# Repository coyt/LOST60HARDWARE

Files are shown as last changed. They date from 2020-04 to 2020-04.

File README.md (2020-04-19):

# LOST60HARDWARE
Hardware design files for LOST60 Bluetooth Mechanical Keyboard

<p align="center">

</p>

<p align="center">

</p>

#### LOST60 PCB Version 2.0 (SPRING 2020)
<p align="center">
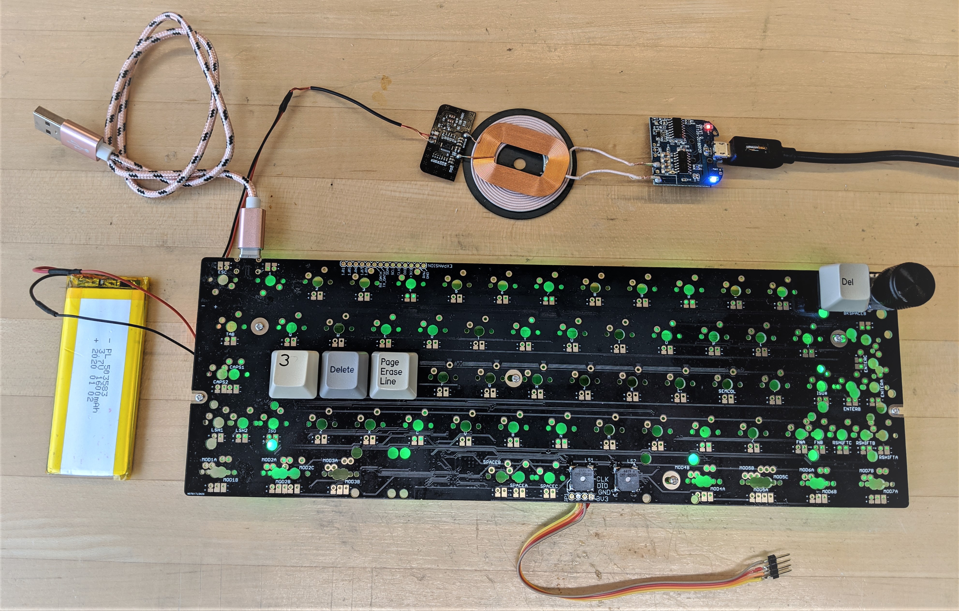
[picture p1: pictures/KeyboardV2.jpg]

</p>

#### LOST60 PCB Version 1.0 (FALL 2019)
<p align="center">

</p>

*The Ultimate Hackable Bluetooth Mechanical Keyboard*

#### Overview

Hardware design files for the LOST60 Bluetooth 60% Mechanical Keyboard PCB. The PCB utilizes a Nordic Semiconductor [nrf52840 bluetooth SoC](https://www.nordicsemi.com/?sc_itemid=%7B2DC10BA5-A76E-40F8-836E-E2FC65803A71%7D) (Rigado BMD-340 module) as the sole processor.

#### PCB Artwork
<p align="center">
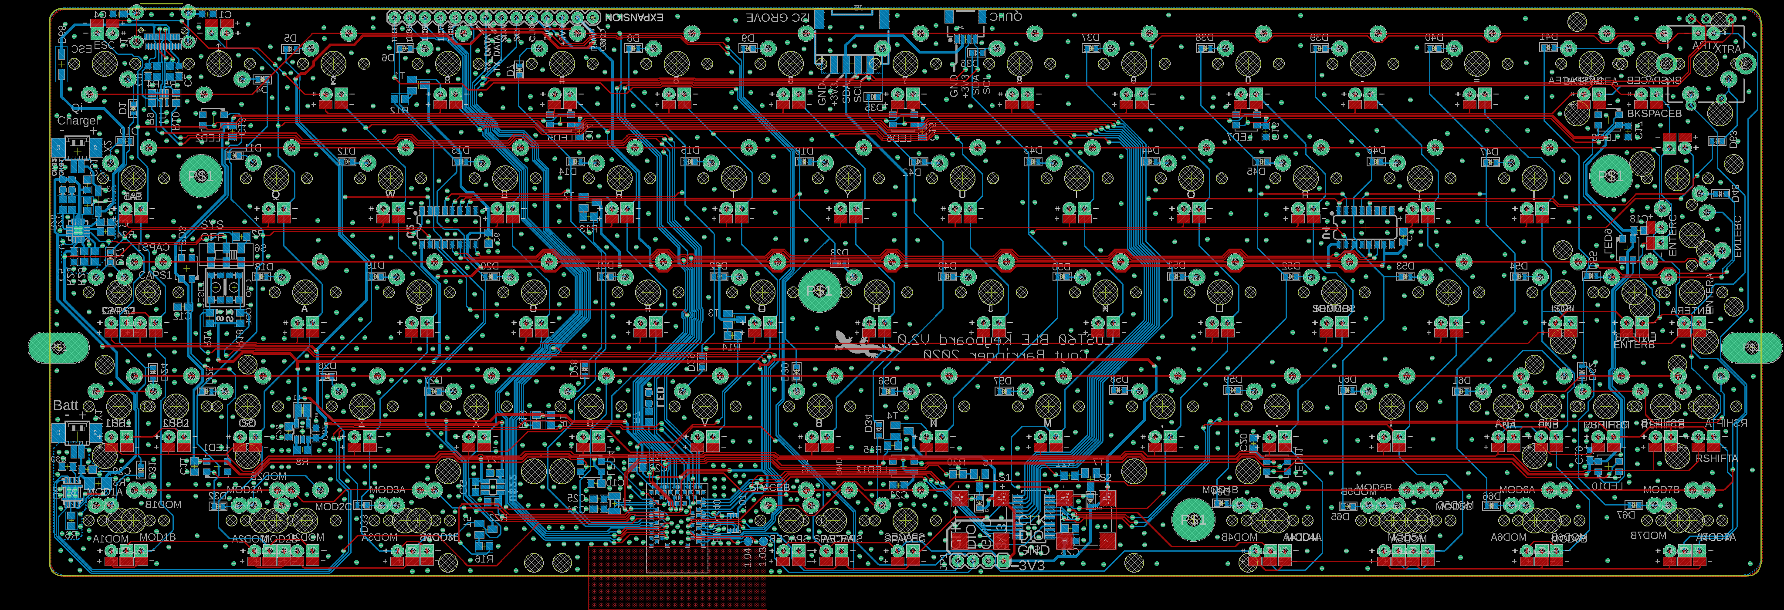
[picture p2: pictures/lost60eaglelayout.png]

</p>

#### 3D Modeling
<p align="center">
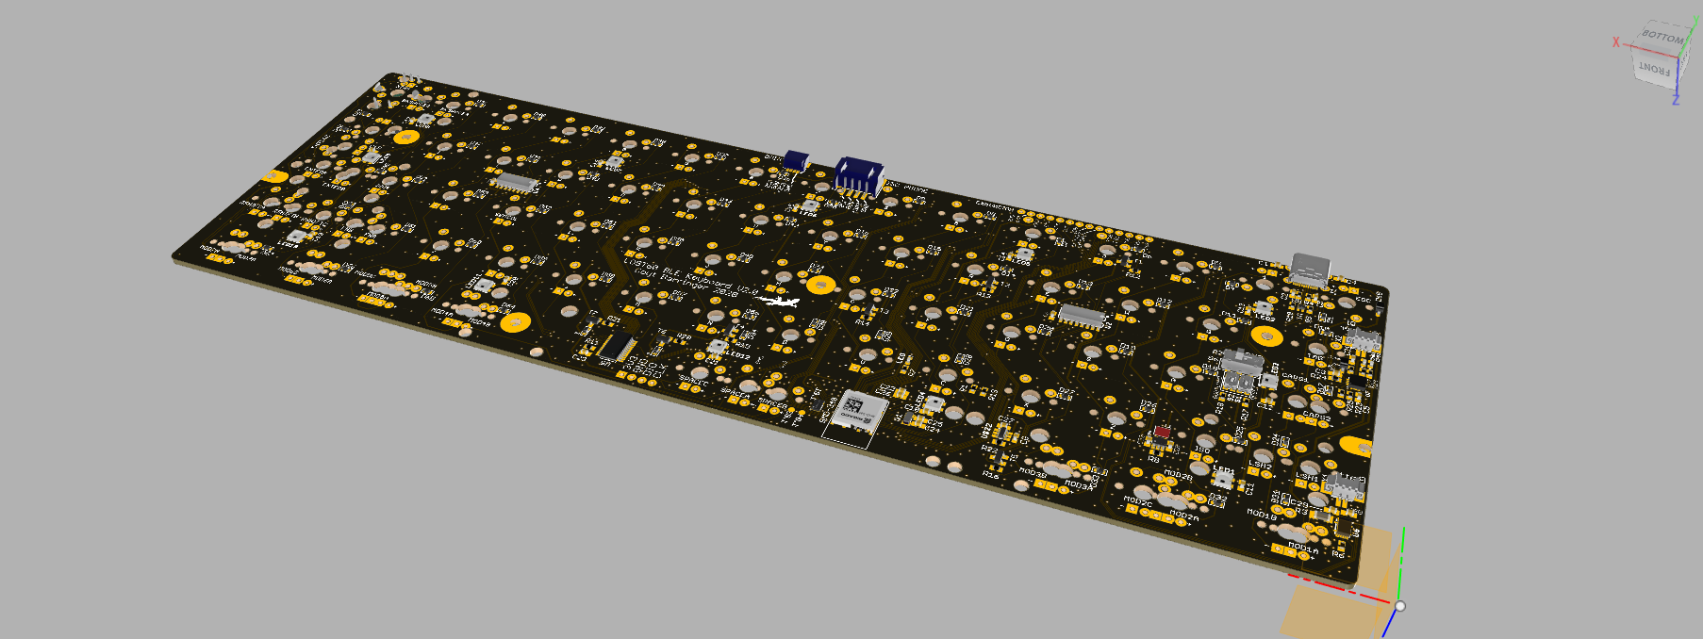
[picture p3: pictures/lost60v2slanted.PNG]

</p>

<p align="center">
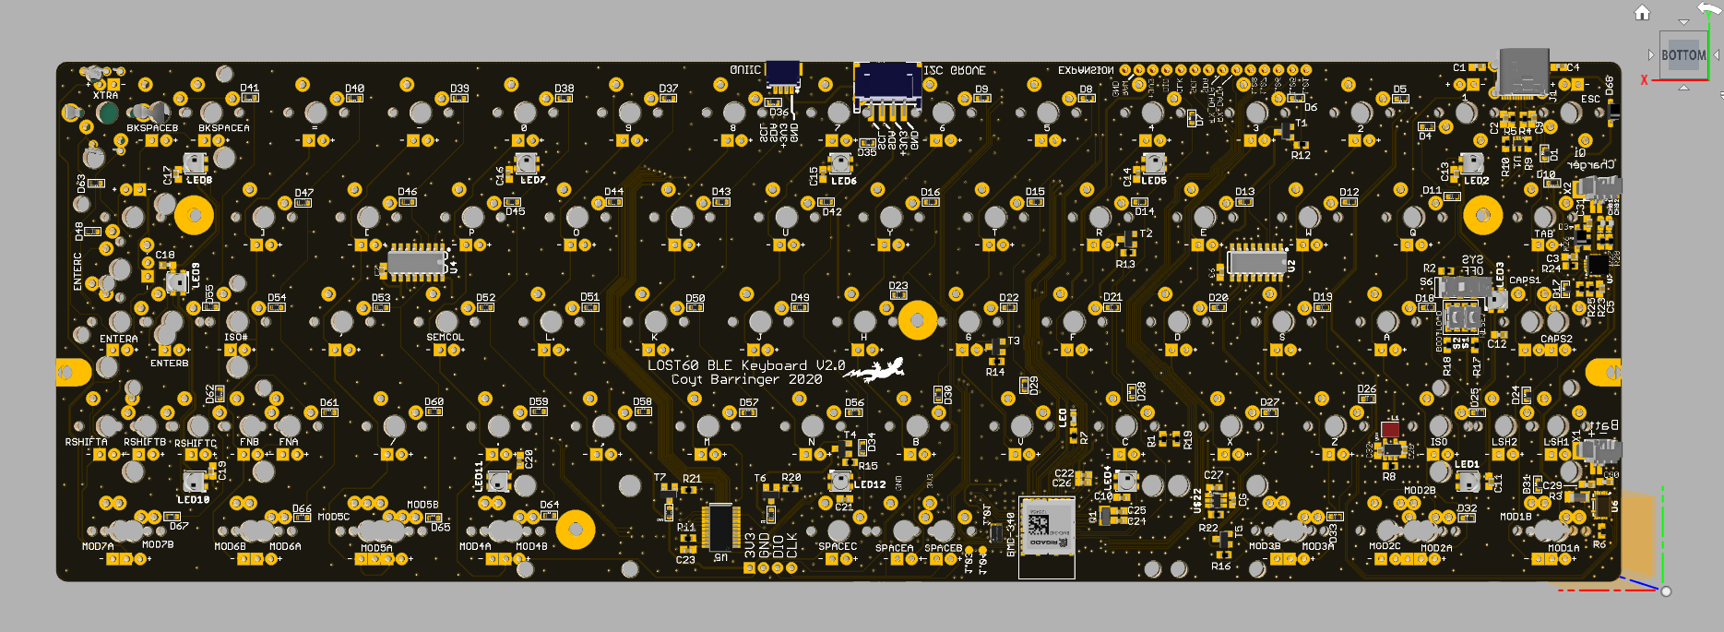
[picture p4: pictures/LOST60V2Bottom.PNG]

</p>

<p align="center">
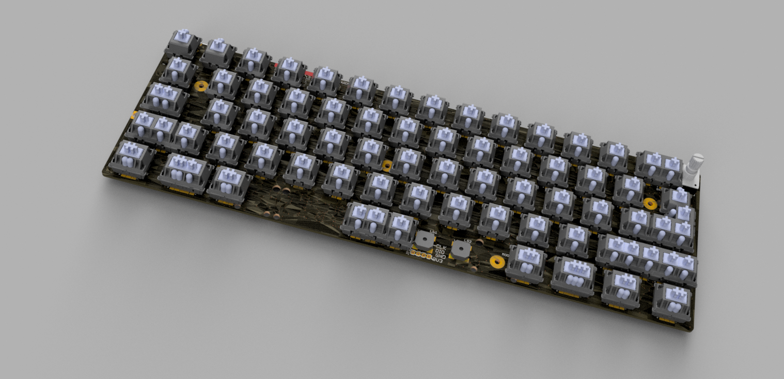
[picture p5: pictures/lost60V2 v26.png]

</p>

#### Version 2.0 System Diagram

<p align="center">
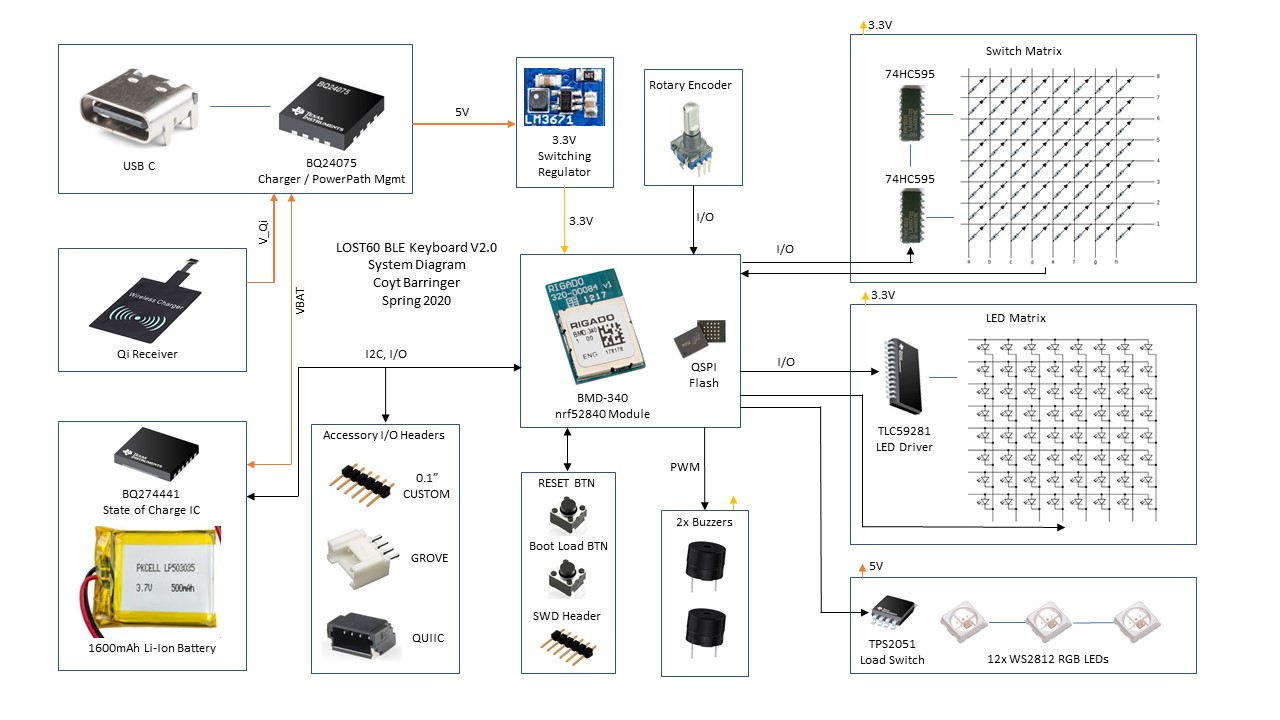
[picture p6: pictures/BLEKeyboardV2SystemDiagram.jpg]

</p>

#### Hardware Features
* 60% Mechanical Keyboard design based on GH60 Layout
* USBC connector
* Bluetooth 5.0 support
* Full RGB underlighting with "neopixels"
* Independently addressable single color key backlingting
* Qi wireless charging
* Advanced battery charging and management circuitry
* Rotary encoder and TWO speakers for Synthesizer features (under development)
* Several expansion ports (QUIIC, GROVE, CUSTOM)

#### Planned Hardware Updates

- [x] Add coulomb counting IC / improve voltage and power measurement   (Complete in V2.0)
- [ ] Improve backlighting LED brightness 
- [x] Extend USB C connector out a bit                                  (Complete in V2.0)
- [x] Fix underlighting load switch fly wire                            (Complete in V2.0)
- [x] Fix LiPo charger ground pour problem & improve charge rate        (Complete in V2.0)
- [x] Remove onboard Lithium protection IC                              (Complete in V2.0)
- [ ] Add physical power switch connection point 
- [ ] Change wiring so I/O emulates Feather nrf52840 board
- [x] Add QSPI memory chip                                              (Complete in V2.0)

#### Development Setup

This design was created using Eagle PCB for schematic capture and PCB layout and routing. Fusion 360 was used to generate CAD model of board before manufacture.

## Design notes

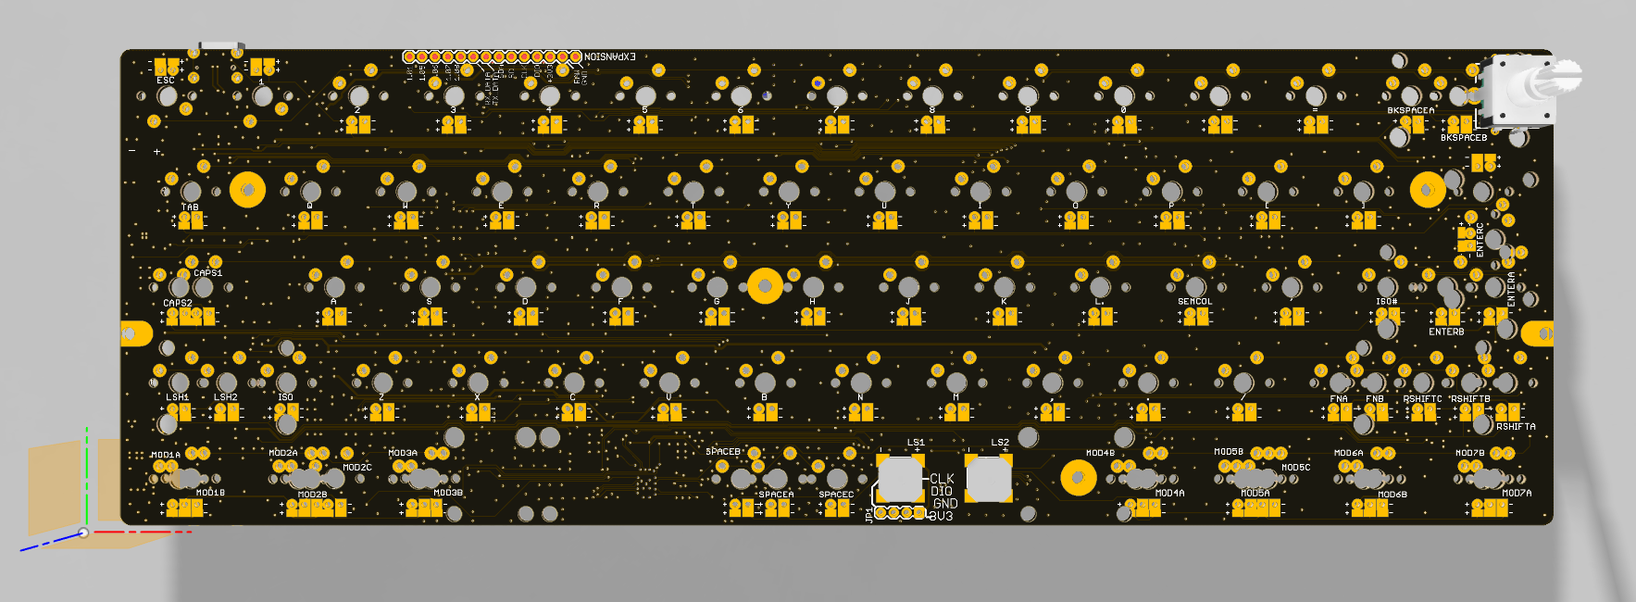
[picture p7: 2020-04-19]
pictures/LOST60V2.PNG

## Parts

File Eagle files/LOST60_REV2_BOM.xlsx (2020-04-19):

Qty | Value | Device | Package | Digikey Part Number | Price Per Part | Part Qty. for price | Total Price | Parts | Description
67 |  | DIODESOD-523 | SOD-523 | 1N4448XTPMSCT-ND | 0.02319 | 1000 | #REF! | D1, D2, D4, D5, D6, D7, D8, D9, D10, D11, D12, D13, D14, D15, D16, D17, D18, D19, D20, D21, D22, D23, D24, D25, D26, D27, D28, D29, D30, D31, D32, D33, D34, D35, D36, D37, D38, D39, D40, D41, D42, D43, D44, D45, D46, D47, D48, D49, D50, D51, D52, D53, D54, D55, D56, D57, D58, D59, D60, D61, D62, D63, D64, D65, D66, D67, D69 | Diode
1 |  | DX07S024JJ2_USB_TYPE-C | DX07S0224JJ2_USB-C | 670-2794-1-ND | 2.372 | 10 | #REF! | J1 | JAE DX07S024JJ2 USB Type-C Connector
1 |  | QWIIC_CONNECTORJS-1MM | 1X04_1MM_RA | 455-1804-1-ND | 0.569 | 10 | #REF! | J4 | SparkFun I2C Standard Qwiic Connector
1 | 0 | R-US_R0603 | R0603 | 311-0.0GRCT-ND | 0.019 | 10 | #REF! | R24 | RESISTOR, American symbol
1 | 0.01 | R-US_R1206 | R1206 | 408-1570-1-ND | 0.385 | 10 | #REF! | R3 | RESISTOR, American symbol
12 | 0.1uF | C-USC0603K | C0603K | 399-1099-1-ND | 0.01152 | 500 | #REF! | C10, C11, C12, C13, C14, C15, C16, C17, C18, C19, C20, C21 | CAPACITOR, American symbol
1 | 0.47uF | C-USC0603K | C0603K | 1276-2082-1-ND | 0.073 | 10 | #REF! | C30 | CAPACITOR, American symbol
1 | 1.1k | R-US_R0603 | R0603 | RMCF0603FT1K10CT-ND | 0.016 | 10 | #REF! | R26 | RESISTOR, American symbol
2 | 100k | R-US_R0603 | R0603 | RR08P100KDCT-ND | 0.093 | 10 | #REF! | R8, R22 | RESISTOR, American symbol
2 | 100pF | C-USC0603K | C0603K | 1292-1644-1-ND | 0.028 | 10 | #REF! | C1, C4 | CAPACITOR, American symbol
3 | 10k | R-US_R0603 | R0603 | 311-10KGRCT-ND | 0.019 | 10 | #REF! | R17, R18, R23 | RESISTOR, American symbol
3 | 10uF | C-USC0603K | C0603K | 587-5869-1-ND | 0.0451 | 100 | #REF! | C5, C26, C31,C32 | CAPACITOR, American symbol
2 | 15pF | C-USC0603K | C0603K | 1292-1487-1-ND | 0.028 | 10 | #REF! | C24, C25 | CAPACITOR, American symbol
2 | 4.7k | R-US_R0603 | R0603 | 311-4.7KGRCT-ND | 0.019 | 10 | #REF! | R1, R19
4 | 1k | R-US_R0603 | R0603 | 311-1.0KGRCT-ND | 0.0077 | 100 | #REF! | R2, R7, R27, R28 | RESISTOR, American symbol
6 | 1uF | C-USC0603K | C0603K | 1276-6524-1-ND | 0.0186 | 100 | #REF! | C3, C6, C7, C22, C23, C27, C29 | CAPACITOR, American symbol
1 | 2.2uH/NRH2412T2R2MNGH | MICROBUILDER_INDUCTORNRH2412T | MICROBUILDER_INDUCTOR_TAIYOYUDEN_NRH2412T | 587-3443-1-ND | 0.203 | 10 | #REF! | L1 | Inductors
1 | 2.7k | R-US_R0603 | R0603 | A129693CT-ND | 0.03 | 10 | #REF! | R6 | RESISTOR, American symbol
1 | 22uF | C-USC0603K | C0603K | 1276-2868-1-ND | 0.173 | 10 | #REF! | C28 | CAPACITOR, American symbol
2 | 3.3uF | C-USC0603K | C0603K | 399-5502-1-ND | 0.171 | 10 | #REF! | C2, C9 | CAPACITOR, American symbol
2 | 30 | R-US_R0603 | R0603 | 311-30GRCT-ND | 0.019 | 10 | #REF! | R9, R10 | RESISTOR, American symbol
1 | 32.768kHz | KX-327-NHF | 3.2X1.5 | 300-8879-1-ND | 0.446 | 10 | #REF! | Q1 | Tuning Fork Crystals (kHz) SMD:
1 | 4.7uF | C-USC0603 | C0603 | 1276-1045-1-ND | 0.055 | 10 | #REF! | CG | CAPACITOR, American symbol
10 | 5.1k | R-US_R0603 | R0603 | P5.10KHCT-ND | 0.0234 | 100 | #REF! | R4, R5, R11, R12, R13, R14, R15, R16, R20, R21 | RESISTOR, American symbol
1 | 590 | R-US_R0603 | R0603 | 311-590HRCT-ND | 0.023 | 10 | #REF! | R25 | RESISTOR, American symbol
7 | BC848 | BC848 | SOT23 | BC848BLT1GOSCT-ND | 0.116 | 10 | #REF! | T1, T2, T3, T4, T5, T6, T7 | NPN TRANSISTOR
1 | BMD-340 | BMD-340 | BMD-340 | 672-BMD-340-A-R-00CT-ND | 12.07 | 10 | #REF! | BMD-340
1 | BQ24075 | BQ24075 | PVQFN-N16 | 296-25609-1-ND | 2.042 | 10 | #REF! | U7 | Texas Instruments BQ24075 LiPo Battery Chargerand Power-Path Management IC
1 | BQ27441-G1 | BQ27441-G1 | PDSO-N12 | 296-39941-1-ND | 2.353 | 10 | #REF! | U6 | Texas Instruments BQ27441-G1 LiPo Battery Fuel Gauge
2 | CMT-8530S-SMT | CMT-8530S-SMT | CUI_CMT-8530S-SMT | 102-3736-1-ND | 2.202 | 25 | #REF! | LS1, LS2 | 8.5 mm, 3.6 Vo-p, 90 dB, Surface Mount (SMT), Magnetic Audio Transducer Buzzer
1 | GD25Q16CEIGR | MICROBUILDER_SPIFLASH_8PINUX | MICROBUILDER_USON8 | 1970-1011-1-ND | 0.552 | 10 | #REF! | U3 | SOIC8 SPI Flash
1 | LM3671 | LM3671 | SOT23-5 | LM3671MF-3.3/NOPBCT-ND | 1.282 | 10 | #REF! | U$38 | Texas Instruments LM3671, LM3671Q 2MHz, 600mA Step-Down DC-DC Converter
2 | MBR120 | D-FILL-SOD123 | SOD123 | SL22PL-TPMSCT-ND | 0.313 | 10 | #REF! | D3, D68 | DIODE
2 | MOLEX_53261-02 | MOLEX_53261-02 | 53261-02 | WM7620CT-ND | 0.86 | 10 | #REF! | X1, X2 | CONNECTOR
2 | MOMENTARY-SWITCH-SPST-SMD-4.6X2.8MM | MOMENTARY-SWITCH-SPST-SMD-4.6X2.8MM | TACTILE_SWITCH_SMD_4.6X2.8MM | CKN11065CT-ND | 0.432 | 10 | #REF! | S1, S2 | Momentary Switch (Pushbutton) - SPST
2 | ORANGE | LED0603 | LED-0603 | SML-D12D1WT86CT-ND | 0.155 | 10 | #REF! | CHG1, CHG2 | LED (Generic)
1 | RED | LED0603 | LED-0603 | 732-4978-1-ND | 0.14 | 1 | #REF! | LED | LED (Generic)
2 | SN74HC595D | 74HC595D | SO16 | 296-14857-1-ND | 0.34 | 10 | #REF! | U2, U4 | 8-Bit Shift Register (Serial to Parallel)
1 | TLC59281DBQR | TLC59281DBQR | SOP63P600X175-28N | 296-25789-6-ND | 1.149 | 10 | #REF! | U5 | 16-Channel LED Driver
1 | TPD3E001DRLR | TPD3E001DRLR | SOT50P160X60-5N | 296-21885-1-ND | 0.433 | 10 | #REF! | U1 | LOW-CAPACITANCE 3-CHANNEL Â±15-kV ESD-PROTECTION ARRAY FOR HIGH-SPEED DATA INTERFACES
1 | TPS22810* | TPS22810* | SOT23-6 | 296-45297-1-ND | 0.545 | 10 | #REF! | U$22 | The TPS22810 is a single channel load switch with
1 | 4P-SMD-2.0-90D | GROVE-CONNECTOR-SMD-90D(4+2P-2.0) | HW4-SMD-2.0-90D |  |  |  | #REF! | J5 | 320110032
1 | JS202011JCQN | JS202011JCQN | JS202011JCQN |  |  |  | #REF! | S6
12 | WS2812B3535 | WS2812B3535 | LED3535 |  |  |  | #REF! | LED1, LED2, LED3, LED4, LED5, LED6, LED7, LED8, LED9, LED10, LED11, LED12
1 | ENCODER-SWITCH-MOD1 | ENCODER-SWITCH-MOD1 | ROTARY_ENC_PLAIN-MOD1 | PEC11R-4220K-S0024-ND | 1.56600 | 10 | #REF! | S4 | Rotary Encoder w/ Select Switch
1 |  | M14 | 1X14 |  |  |  | #REF! | JP2 | Header 14
 | Top components: | 95
 | Bottom components: | 173 |  |  |  |  | #REF!
 | Total Pads: | 1124

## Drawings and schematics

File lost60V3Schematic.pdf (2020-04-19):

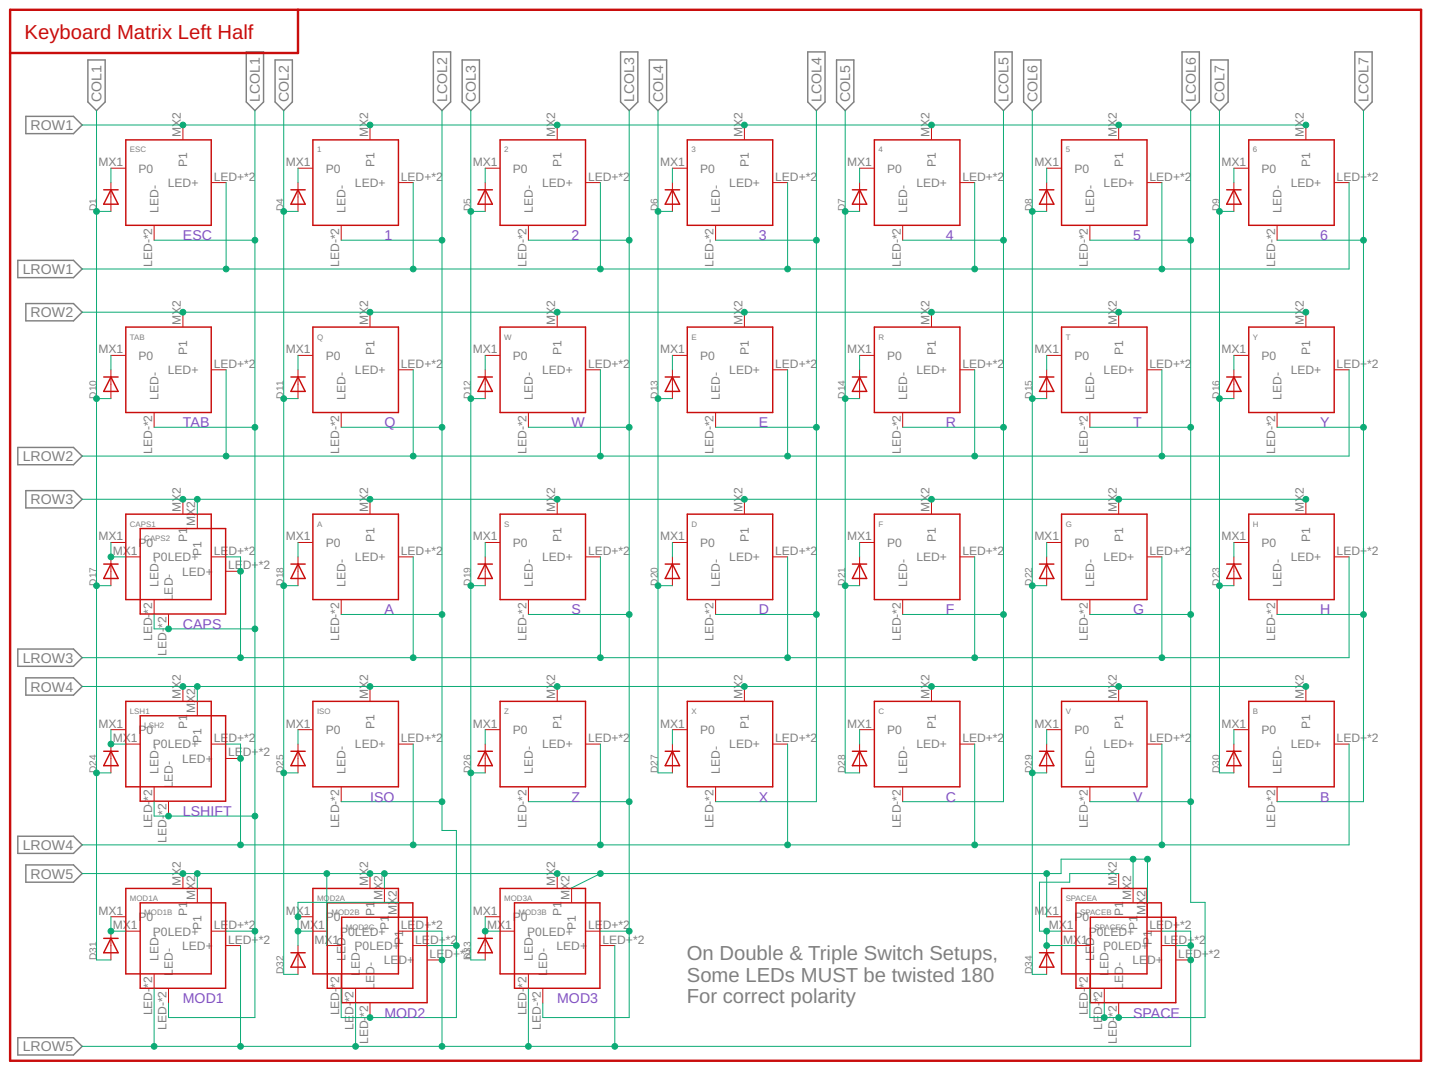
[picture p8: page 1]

Keyboard Matrix Left Half

On Double & Triple Switch Setups, Some LEDs MUST be twisted 180

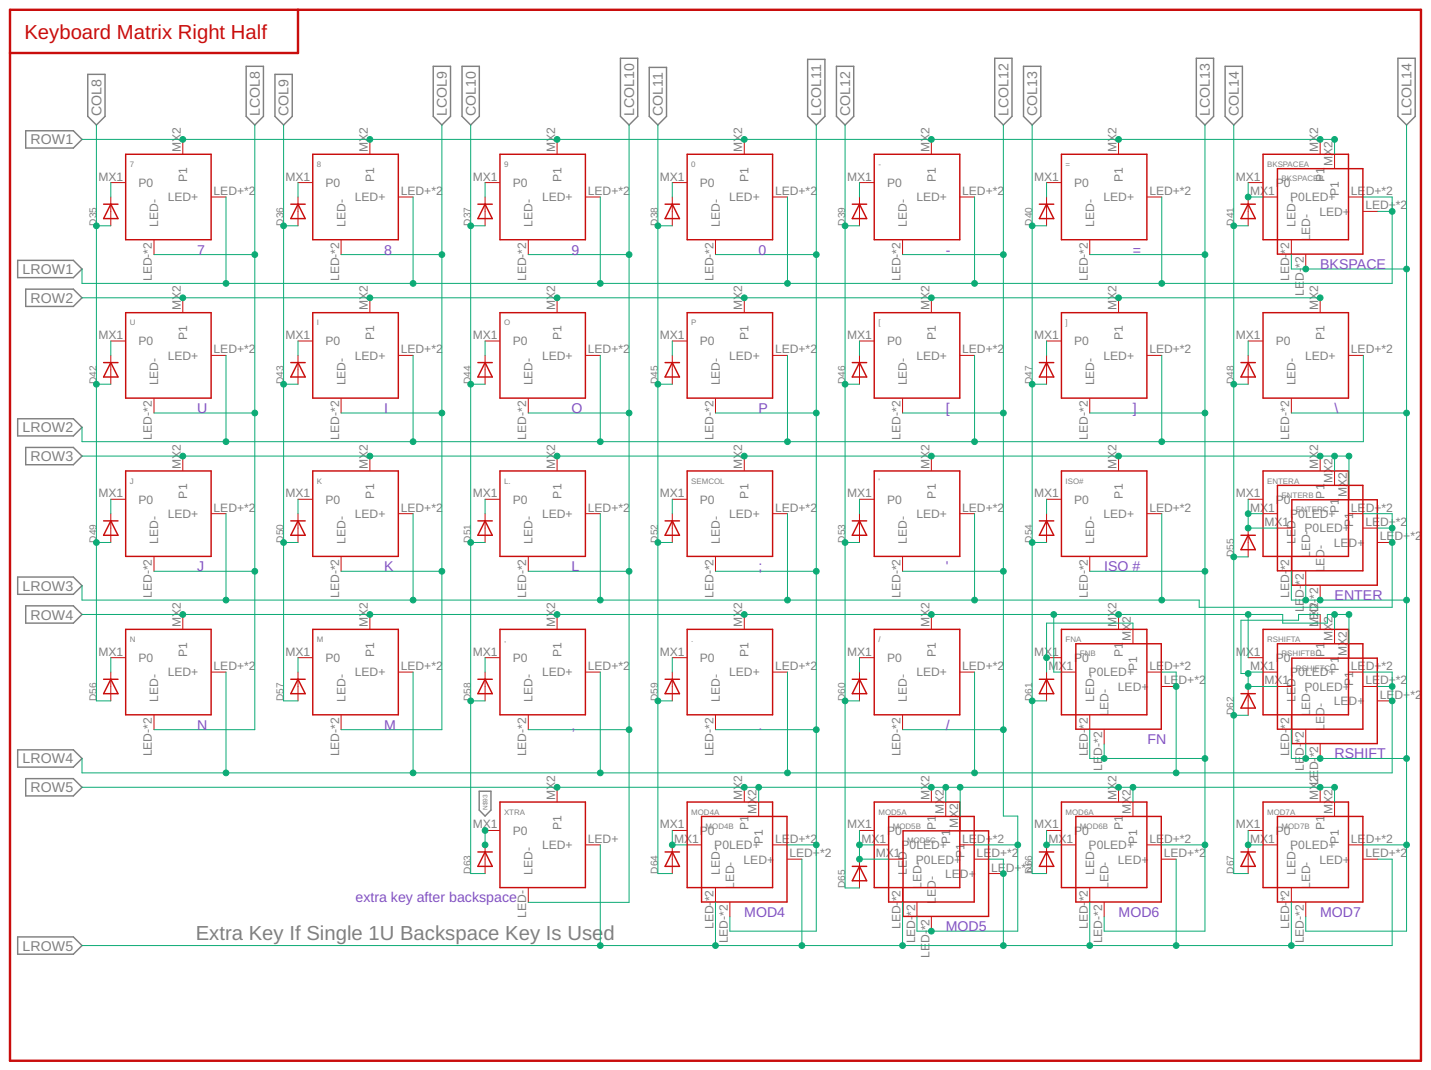
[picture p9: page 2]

Keyboard Matrix Right Half

ENTERB
LED+ | LED+*2

Extra Key If Single 1U Backspace Key Is Used

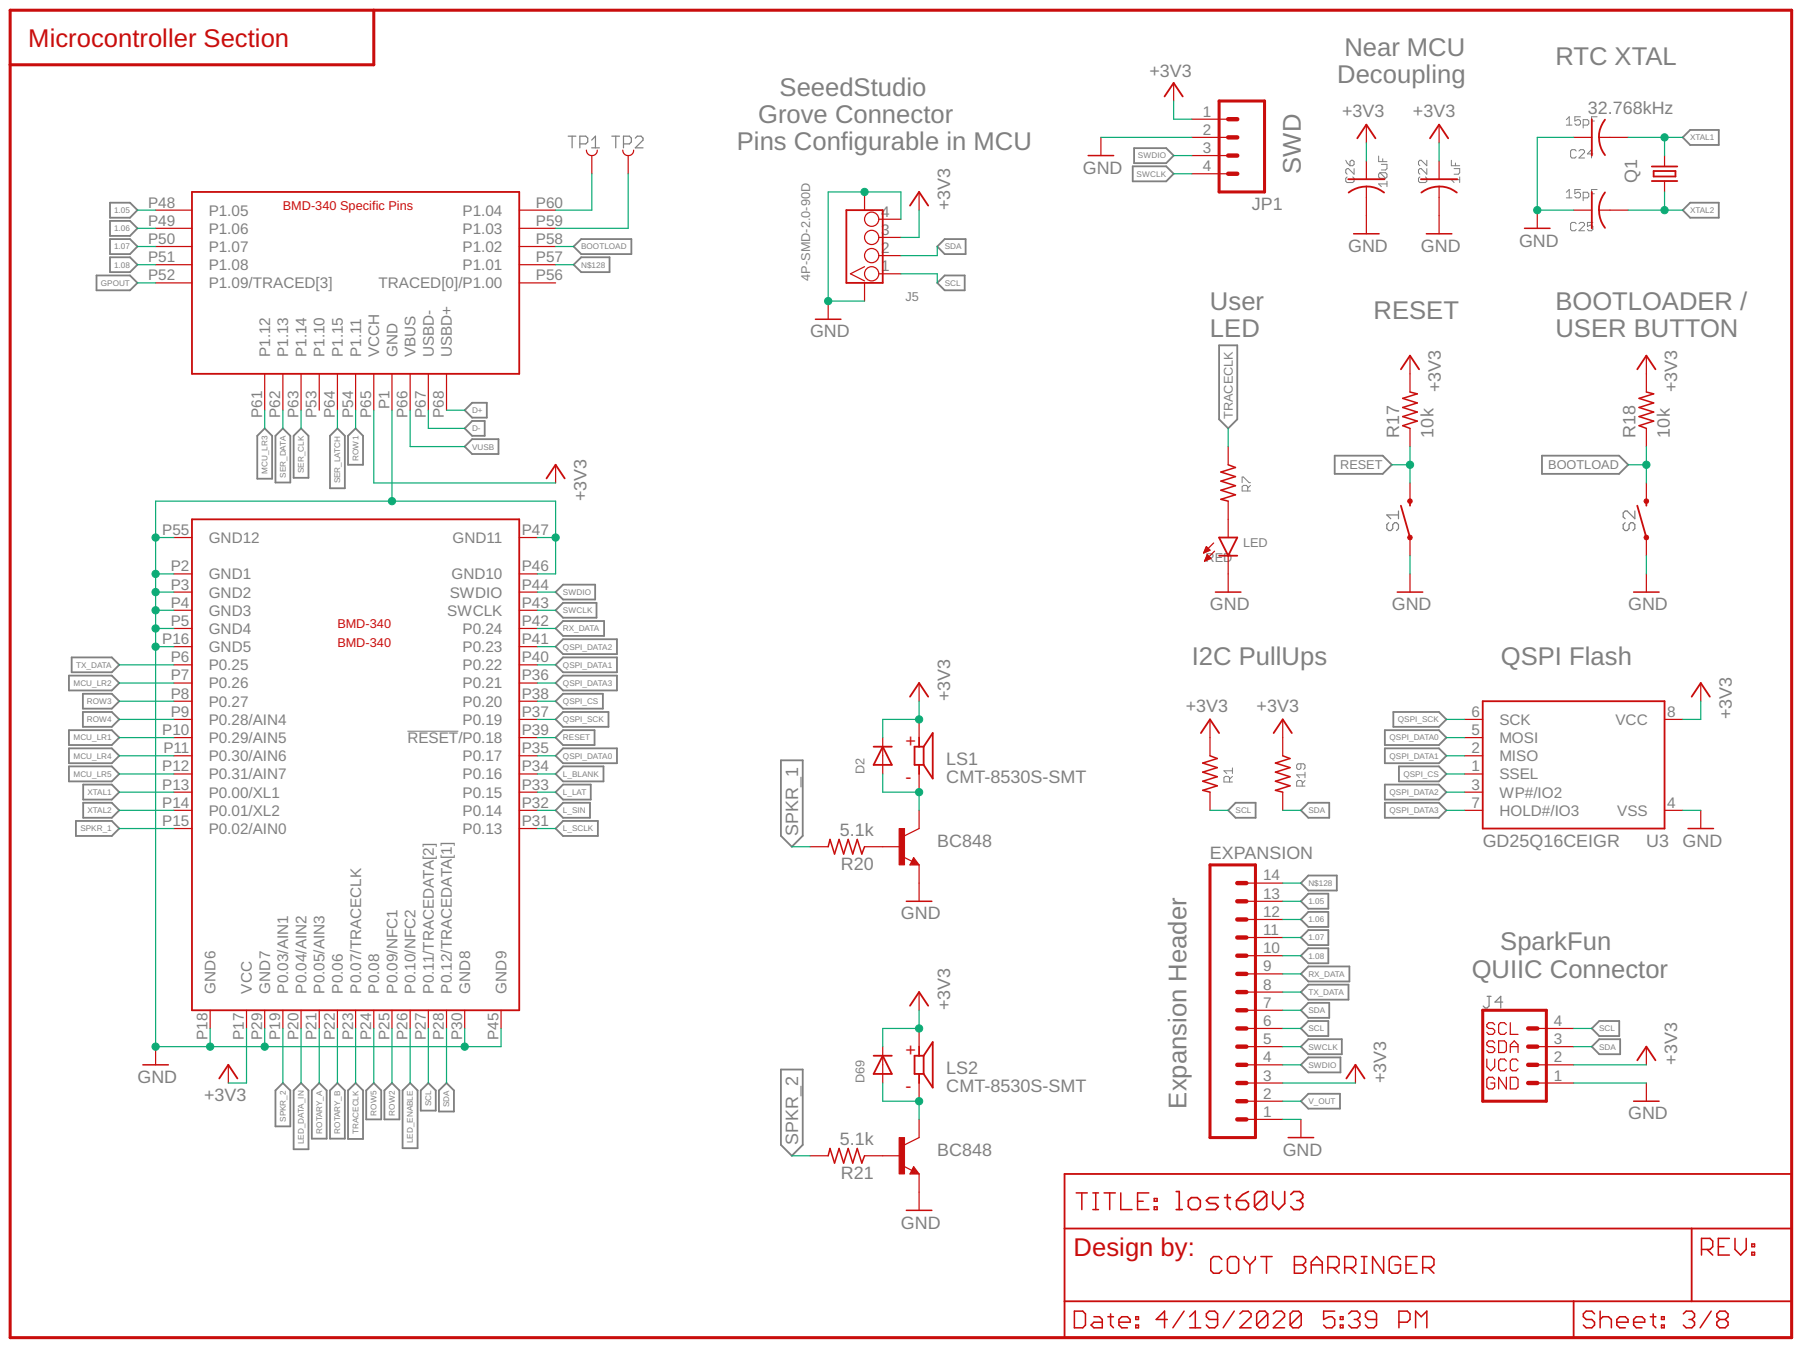
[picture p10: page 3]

SeeedStudio
Grove Connector
Pins Configurable in MCU

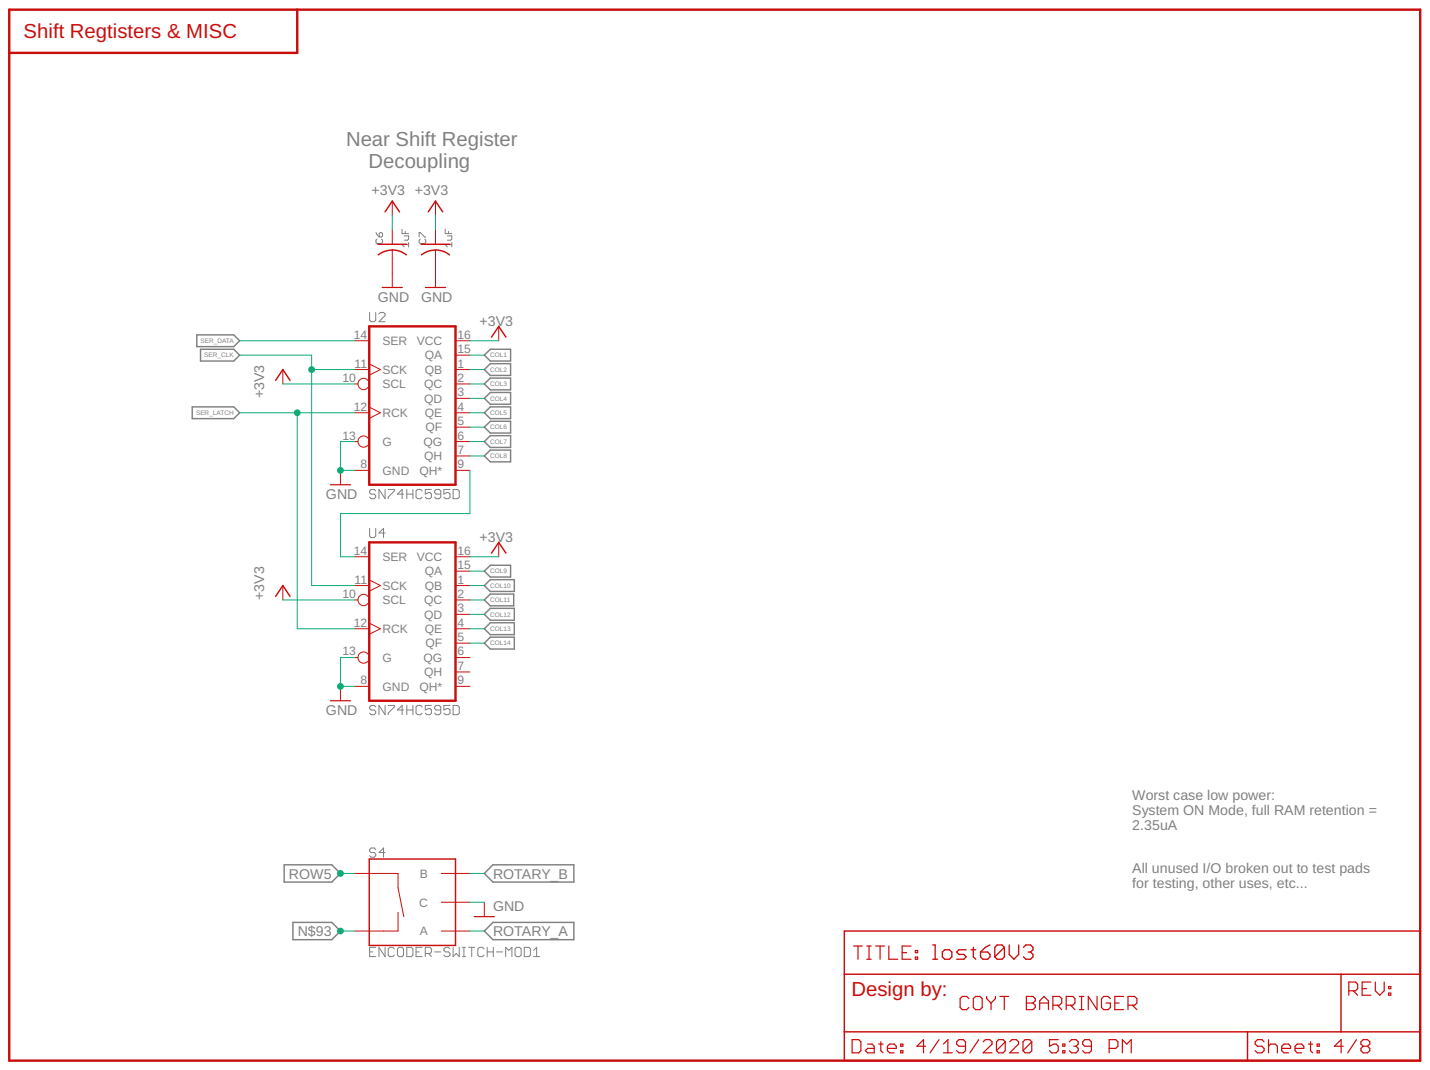
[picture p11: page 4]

for testing, other uses, etc... Worst case low power: System ON Mode, full RAM retention =

All unused I/O broken out to test pads

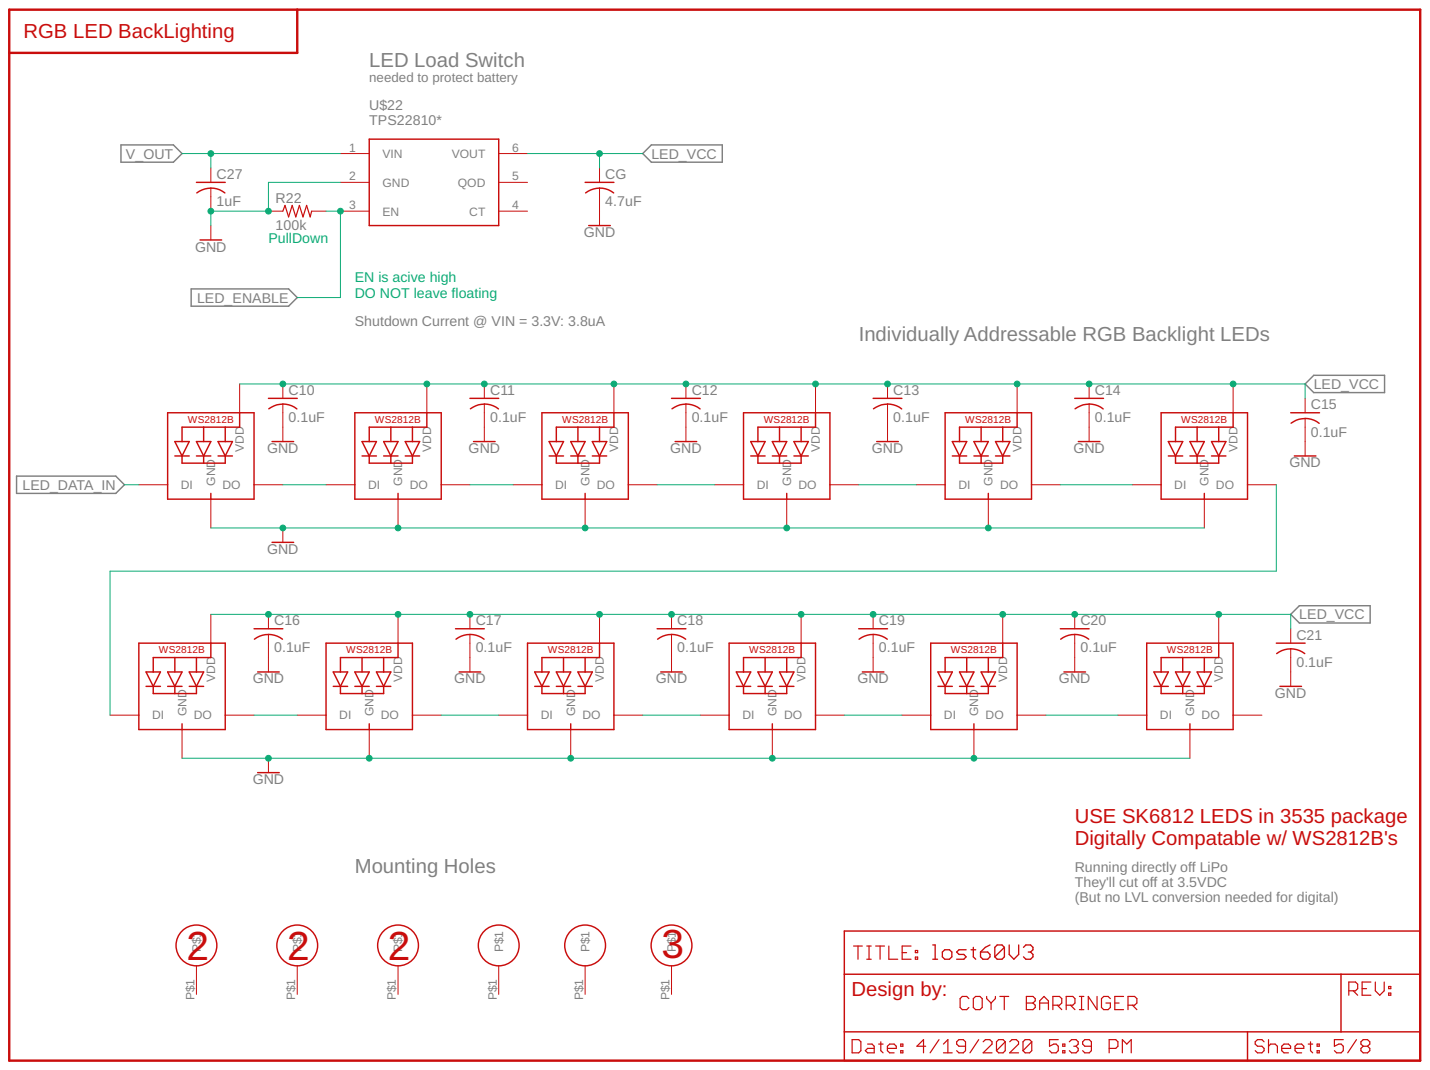
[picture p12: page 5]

LED Load Switch
needed to protect battery

EN is acive high
DO NOT leave floating

Individually Addressable RGB Backlight LEDs

USE SK6812 LEDS in 3535 package
Digitally Compatable w/ WS2812B's

Running directly off LiPo They'll cut off at 3.5VDC

(But no LVL conversion needed for digital)

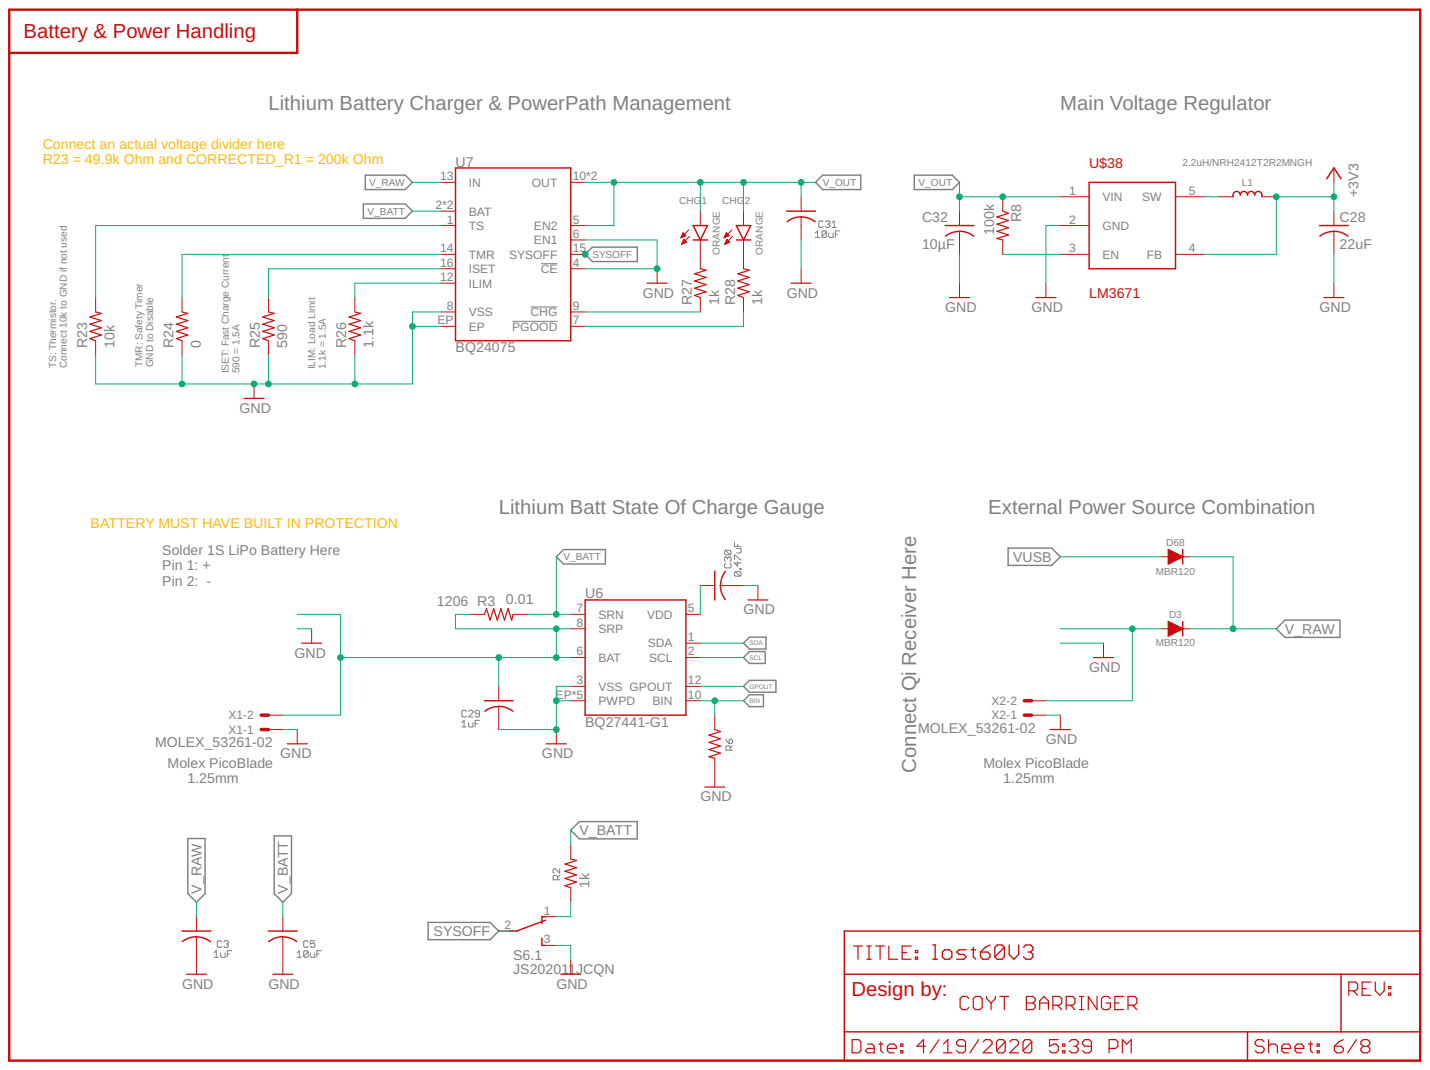
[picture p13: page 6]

Connect an actual voltage divider here R23 = 49.9k Ohm and CORRECTED_R1 = 200k Ohm

TS: Thermistor. Connect 10k to GND if not used TMR: Safety Timer GND to Disable

ISET: Fast Charge Current 590 = 1.5A

Lithium Batt State Of Charge Gauge

External Power Source Combination

BATTERY MUST HAVE BUILT IN PROTECTION

Solder 1S LiPo Battery Here Pin 1: + Pin 2: -

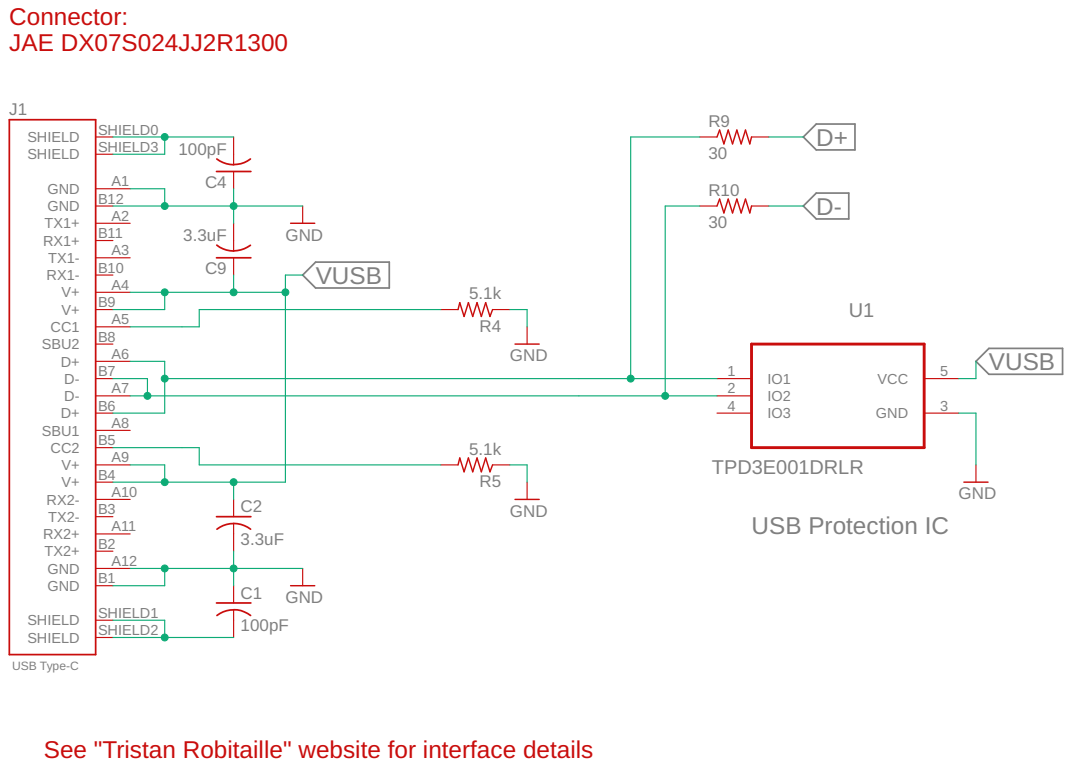
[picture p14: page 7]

See "Tristan Robitaille" website for interface details

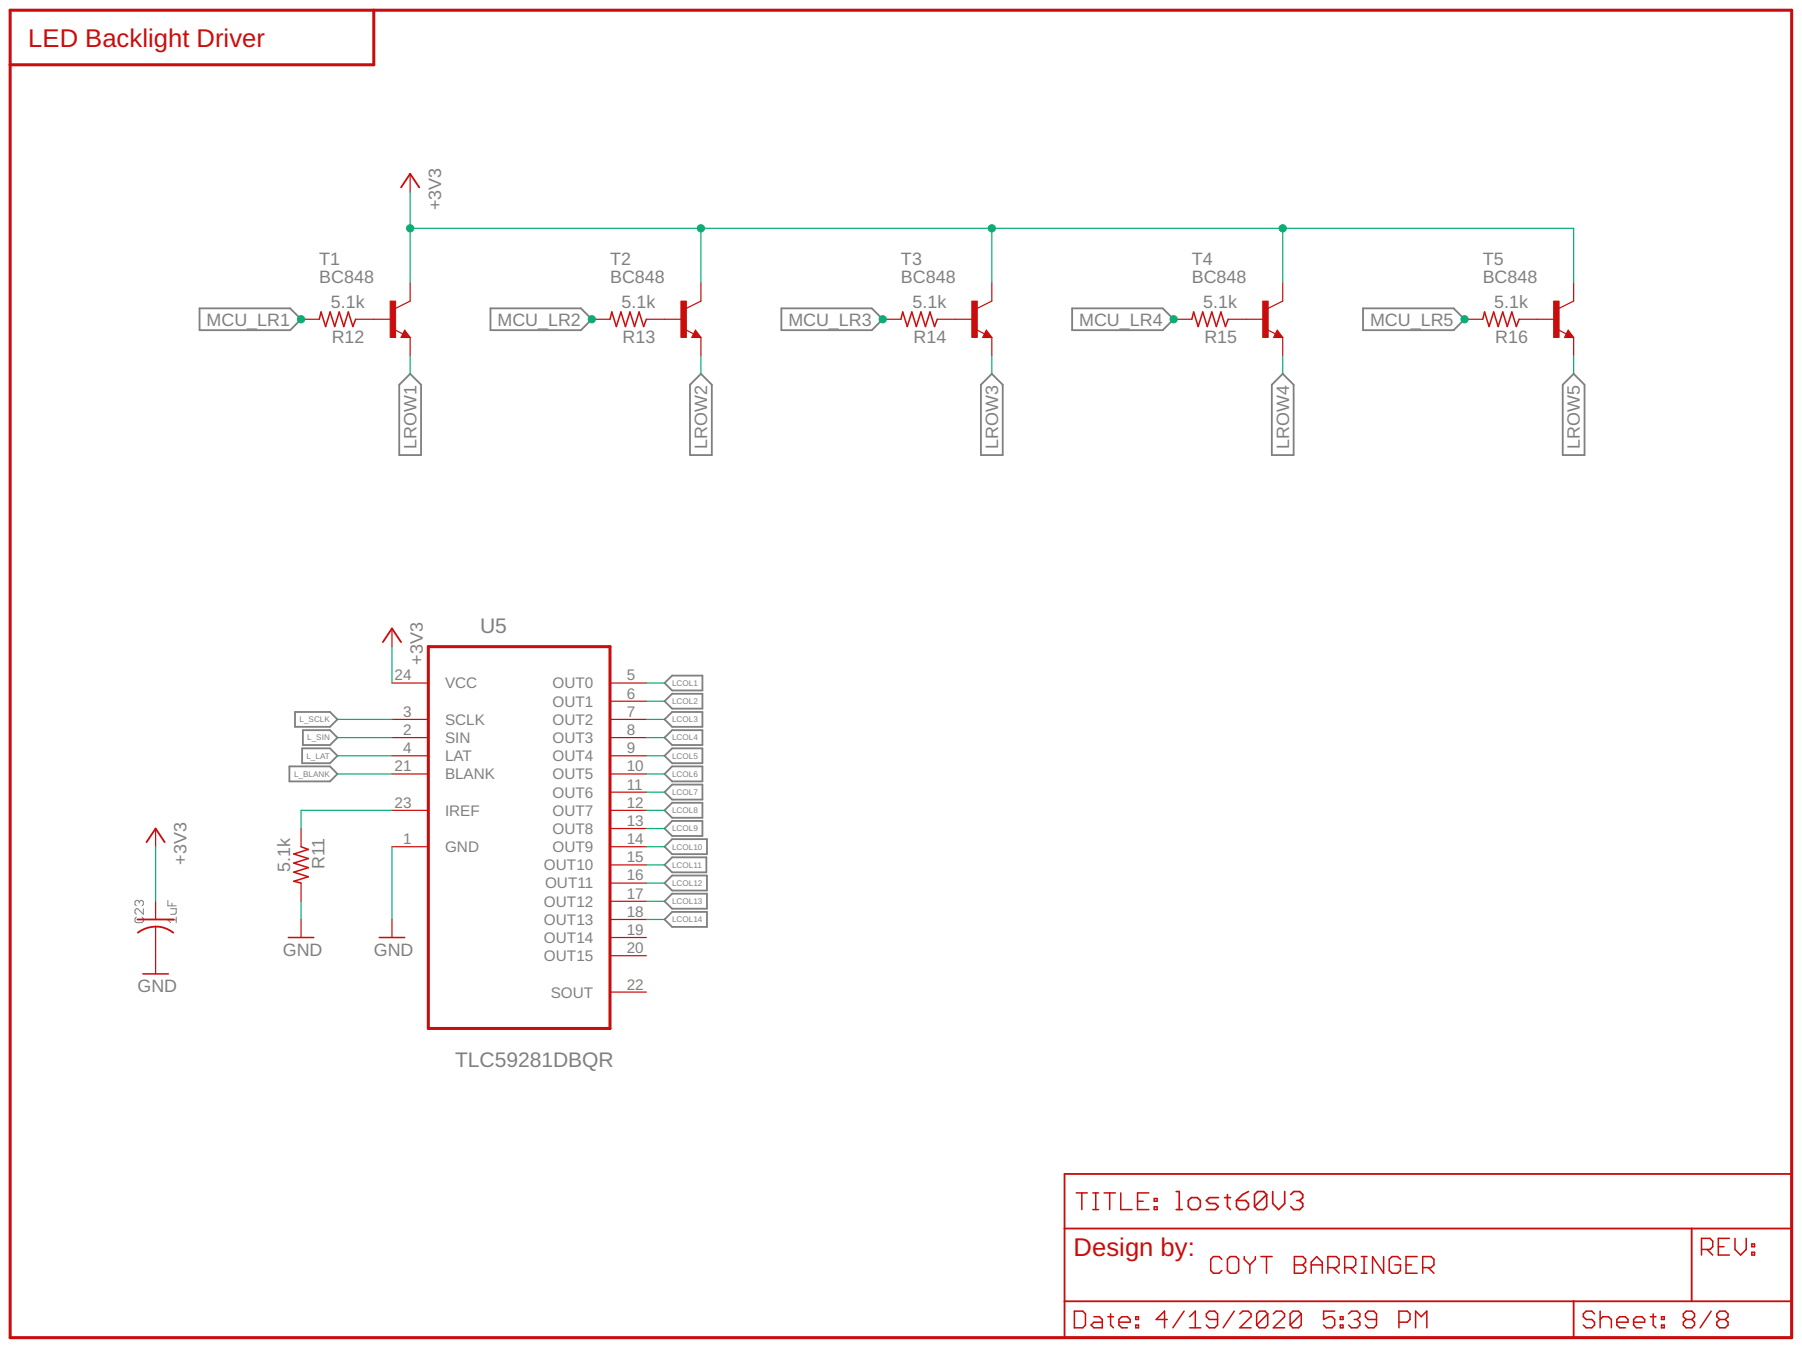
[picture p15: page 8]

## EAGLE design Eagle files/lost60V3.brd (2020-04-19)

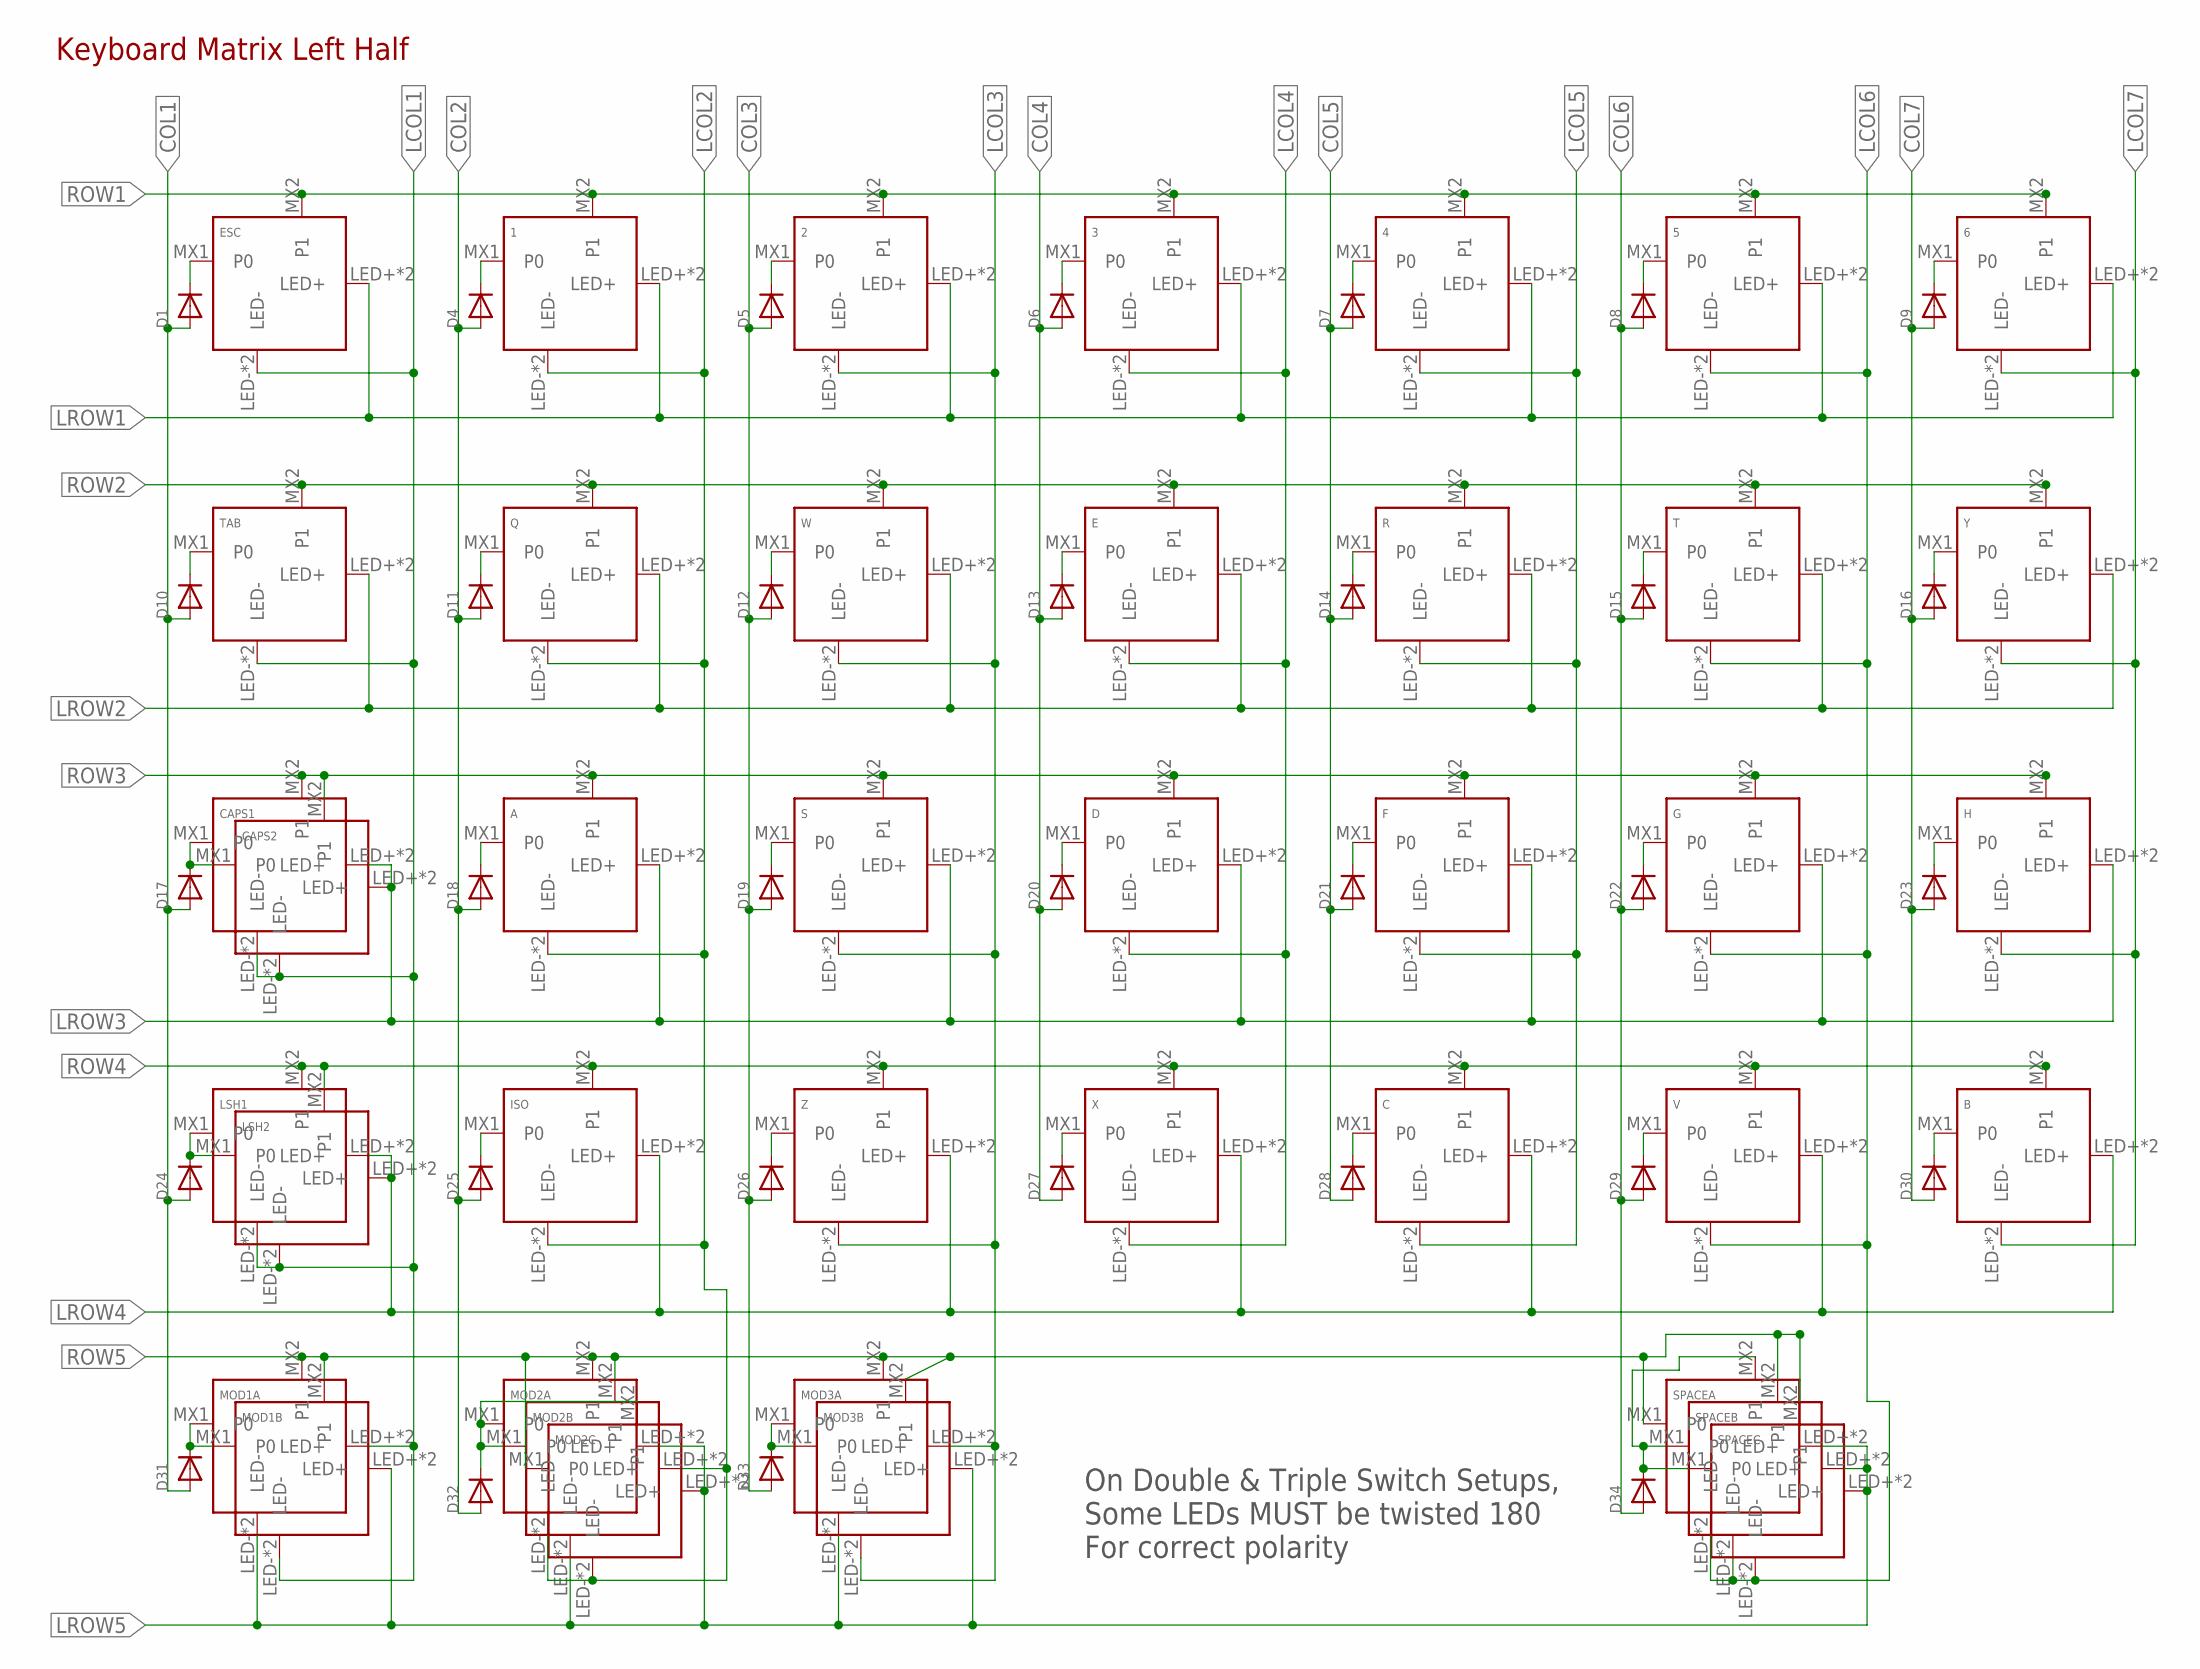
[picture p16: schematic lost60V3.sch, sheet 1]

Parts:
1, 2, 3, 4, 5, 6: KEYSWITCH-THTSMDLED-MX-1U-THTSMDLED; MX-1U-THTSMDLED
A: KEYSWITCH-THTSMDLED-MX-1U-THTSMDLED; MX-1U-THTSMDLED
B: KEYSWITCH-THTSMDLED-MX-1U-THTSMDLED; MX-1U-THTSMDLED
C: KEYSWITCH-THTSMDLED-MX-1U-THTSMDLED; MX-1U-THTSMDLED
CAPS1, CAPS2: KEYSWITCH-THTSMDLED-MX-1U-THTSMDLED; MX-1U-THTSMDLED
D: KEYSWITCH-THTSMDLED-MX-1U-THTSMDLED; MX-1U-THTSMDLED
D1, D4, D5, D6, D7, D8, D9, D10, D11, D12, D13, D14, D15, D16, D17, D18, D19, D20, D21, D22, D23, D24, D25, D26, D27, D28, D29, D30, D31, D32, D33, D34: DIODESOD-523; SOD-523
E: KEYSWITCH-THTSMDLED-MX-1U-THTSMDLED; MX-1U-THTSMDLED
ESC: KEYSWITCH-THTSMDLED-MX-1U-THTSMDLED; MX-1U-THTSMDLED
F: KEYSWITCH-THTSMDLED-MX-1U-THTSMDLED; MX-1U-THTSMDLED
G: KEYSWITCH-THTSMDLED-MX-1U-THTSMDLED; MX-1U-THTSMDLED
H: KEYSWITCH-THTSMDLED-MX-1U-THTSMDLED; MX-1U-THTSMDLED
ISO: KEYSWITCH-THTSMDLED-MX-1U-THTSMDLED; MX-1U-THTSMDLED
LSH1: KEYSWITCH-THTSMDLED-MX-1U-THTSMDLED; MX-1U-THTSMDLED
LSH2: KEYSWITCH-THTSMDLED-MX-2U-THTSMDLED; MX-2U-THTSMDLED
MOD1A, MOD1B, MOD2A, MOD2B, MOD2C, MOD3A, MOD3B: KEYSWITCH-THTSMDLED-MX-1U-THTSMDLED; MX-1U-THTSMDLED
Q: KEYSWITCH-THTSMDLED-MX-1U-THTSMDLED; MX-1U-THTSMDLED
R: KEYSWITCH-THTSMDLED-MX-1U-THTSMDLED; MX-1U-THTSMDLED
S: KEYSWITCH-THTSMDLED-MX-1U-THTSMDLED; MX-1U-THTSMDLED
SPACEA: KEYSWITCH-THTSMDLED-MX-6.25U-THTSMDLED-FLIPPED; MX-6.25U-THTSMDLED-FLIPPED
SPACEB: KEYSWITCH-THTSMDLED-MX-7U-THTSMDLED-FLIPPED; MX-7U-THTSMDLED-FLIPPED
SPACEC: KEYSWITCH-THTSMDLED-MX-7U-THTSMDLED-FLIPPED; MX-7U-THTSMDLED-FLIPPED
T: KEYSWITCH-THTSMDLED-MX-1U-THTSMDLED; MX-1U-THTSMDLED
TAB: KEYSWITCH-THTSMDLED-MX-1U-THTSMDLED; MX-1U-THTSMDLED
V: KEYSWITCH-THTSMDLED-MX-1U-THTSMDLED; MX-1U-THTSMDLED
W: KEYSWITCH-THTSMDLED-MX-1U-THTSMDLED; MX-1U-THTSMDLED
X: KEYSWITCH-THTSMDLED-MX-1U-THTSMDLED; MX-1U-THTSMDLED
Y: KEYSWITCH-THTSMDLED-MX-1U-THTSMDLED; MX-1U-THTSMDLED
Z: KEYSWITCH-THTSMDLED-MX-1U-THTSMDLED; MX-1U-THTSMDLED

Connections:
COL1: D1.A, D10.A, D17.A, D24.A, D31.A; also elsewhere on the board
COL2: D4.A, D11.A, D18.A, D25.A, D32.A; also elsewhere on the board
COL3: D5.A, D12.A, D19.A, D26.A, D33.A; also elsewhere on the board
COL4: D6.A, D13.A, D20.A, D27.A; also elsewhere on the board
COL5: D7.A, D14.A, D21.A, D28.A; also elsewhere on the board
COL6: D8.A, D15.A, D22.A, D29.A, D34.A; also elsewhere on the board
COL7: D9.A, D16.A, D23.A, D30.A; also elsewhere on the board
LCOL1: CAPS1.LED-, CAPS1.SMDLED- (LED-), CAPS2.LED-, CAPS2.SMDLED- (LED-), ESC.LED-, ESC.SMDLED- (LED-), LSH1.LED-, LSH1.SMDLED- (LED-), LSH2.LED-, LSH2.SMDLED- (LED-), MOD1A.LED+, MOD1A.SMDLED+ (LED+), MOD1B.LED-, MOD1B.SMDLED- (LED-), TAB.LED-, TAB.SMDLED- (LED-); also elsewhere on the board
LCOL2: 1.LED-, 1.SMDLED- (LED-), A.LED-, A.SMDLED- (LED-), ISO.LED-, ISO.SMDLED- (LED-), MOD2A.LED-, MOD2A.SMDLED- (LED-), MOD2B.LED+, MOD2B.SMDLED+ (LED+), MOD2C.LED-, MOD2C.SMDLED- (LED-), Q.LED-, Q.SMDLED- (LED-); also elsewhere on the board
LCOL3: 2.LED-, 2.SMDLED- (LED-), MOD3A.LED+, MOD3A.SMDLED+ (LED+), MOD3B.LED-, MOD3B.SMDLED- (LED-), S.LED-, S.SMDLED- (LED-), W.LED-, W.SMDLED- (LED-), Z.LED-, Z.SMDLED- (LED-); also elsewhere on the board
LCOL4: 3.LED-, 3.SMDLED- (LED-), D.LED-, D.SMDLED- (LED-), E.LED-, E.SMDLED- (LED-), X.LED-, X.SMDLED- (LED-); also elsewhere on the board
LCOL5: 4.LED-, 4.SMDLED- (LED-), C.LED-, C.SMDLED- (LED-), F.LED-, F.SMDLED- (LED-), R.LED-, R.SMDLED- (LED-); also elsewhere on the board
LCOL6: 5.LED-, 5.SMDLED- (LED-), G.LED-, G.SMDLED- (LED-), SPACEA.LED-, SPACEA.SMDLED- (LED-), SPACEB.LED-, SPACEB.SMDLED- (LED-), SPACEC.LED-, SPACEC.SMDLED- (LED-), T.LED-, T.SMDLED- (LED-), V.LED-, V.SMDLED- (LED-); also elsewhere on the board
LCOL7: 6.LED-, 6.SMDLED- (LED-), B.LED-, B.SMDLED- (LED-), H.LED-, H.SMDLED- (LED-), Y.LED-, Y.SMDLED- (LED-); also elsewhere on the board
LROW1: 1.LED+, 1.SMDLED+ (LED+), 2.LED+, 2.SMDLED+ (LED+), 3.LED+, 3.SMDLED+ (LED+), 4.LED+, 4.SMDLED+ (LED+), 5.LED+, 5.SMDLED+ (LED+), 6.LED+, 6.SMDLED+ (LED+), ESC.LED+, ESC.SMDLED+ (LED+); also elsewhere on the board
LROW2: E.LED+, E.SMDLED+ (LED+), Q.LED+, Q.SMDLED+ (LED+), R.LED+, R.SMDLED+ (LED+), T.LED+, T.SMDLED+ (LED+), TAB.LED+, TAB.SMDLED+ (LED+), W.LED+, W.SMDLED+ (LED+), Y.LED+, Y.SMDLED+ (LED+); also elsewhere on the board
LROW3: A.LED+, A.SMDLED+ (LED+), CAPS1.LED+, CAPS1.SMDLED+ (LED+), CAPS2.LED+, CAPS2.SMDLED+ (LED+), D.LED+, D.SMDLED+ (LED+), F.LED+, F.SMDLED+ (LED+), G.LED+, G.SMDLED+ (LED+), H.LED+, H.SMDLED+ (LED+), S.LED+, S.SMDLED+ (LED+); also elsewhere on the board
LROW4: B.LED+, B.SMDLED+ (LED+), C.LED+, C.SMDLED+ (LED+), ISO.LED+, ISO.SMDLED+ (LED+), LSH1.LED+, LSH1.SMDLED+ (LED+), LSH2.LED+, LSH2.SMDLED+ (LED+), V.LED+, V.SMDLED+ (LED+), X.LED+, X.SMDLED+ (LED+), Z.LED+, Z.SMDLED+ (LED+); also elsewhere on the board
LROW5: MOD1A.LED-, MOD1A.SMDLED- (LED-), MOD1B.LED+, MOD1B.SMDLED+ (LED+), MOD2A.LED+, MOD2A.SMDLED+ (LED+), MOD2B.LED-, MOD2B.SMDLED- (LED-), MOD2C.LED+, MOD2C.SMDLED+ (LED+), MOD3A.LED-, MOD3A.SMDLED- (LED-), MOD3B.LED+, MOD3B.SMDLED+ (LED+), SPACEA.LED+, SPACEA.SMDLED+ (LED+), SPACEB.LED+, SPACEB.SMDLED+ (LED+), SPACEC.LED+, SPACEC.SMDLED+ (LED+); also elsewhere on the board
unnamed: D1.K (C), ESC.MX1 (P0)
unnamed: 1.MX1 (P0), D4.K (C)
unnamed: 2.MX1 (P0), D5.K (C)
unnamed: 3.MX1 (P0), D6.K (C)
unnamed: 4.MX1 (P0), D7.K (C)
unnamed: 5.MX1 (P0), D8.K (C)
unnamed: 6.MX1 (P0), D9.K (C)
unnamed: D10.K (C), TAB.MX1 (P0)
unnamed: D11.K (C), Q.MX1 (P0)
unnamed: D12.K (C), W.MX1 (P0)
unnamed: D13.K (C), E.MX1 (P0)
unnamed: D14.K (C), R.MX1 (P0)
unnamed: D15.K (C), T.MX1 (P0)
unnamed: D16.K (C), Y.MX1 (P0)
unnamed: D34.K (C), SPACEA.MX2 (P1), SPACEB.MX1 (P0), SPACEC.MX1 (P0)
unnamed: CAPS1.MX1 (P0), CAPS2.MX1 (P0), D17.K (C)
unnamed: A.MX1 (P0), D18.K (C)
unnamed: D19.K (C), S.MX1 (P0)
unnamed: D.MX1 (P0), D20.K (C)
unnamed: D21.K (C), F.MX1 (P0)
unnamed: D23.K (C), H.MX1 (P0)
unnamed: D24.K (C), LSH1.MX1 (P0), LSH2.MX1 (P0)
unnamed: D25.K (C), ISO.MX1 (P0)
unnamed: D26.K (C), Z.MX1 (P0)
unnamed: D27.K (C), X.MX1 (P0)
unnamed: C.MX1 (P0), D28.K (C)
unnamed: D29.K (C), V.MX1 (P0)
unnamed: B.MX1 (P0), D30.K (C)
unnamed: D31.K (C), MOD1A.MX1 (P0), MOD1B.MX1 (P0)
unnamed: D32.K (C), MOD2A.MX1 (P0), MOD2B.MX1 (P0), MOD2C.MX2 (P1)
unnamed: D33.K (C), MOD3A.MX1 (P0), MOD3B.MX1 (P0)
unnamed: D22.K (C), G.MX1 (P0)
ROW1: 1.MX2 (P1), 2.MX2 (P1), 3.MX2 (P1), 4.MX2 (P1), 5.MX2 (P1), 6.MX2 (P1), ESC.MX2 (P1); also elsewhere on the board
ROW2: E.MX2 (P1), Q.MX2 (P1), R.MX2 (P1), T.MX2 (P1), TAB.MX2 (P1), W.MX2 (P1), Y.MX2 (P1); also elsewhere on the board
ROW3: A.MX2 (P1), CAPS1.MX2 (P1), CAPS2.MX2 (P1), D.MX2 (P1), F.MX2 (P1), G.MX2 (P1), H.MX2 (P1), S.MX2 (P1); also elsewhere on the board
ROW4: B.MX2 (P1), C.MX2 (P1), ISO.MX2 (P1), LSH1.MX2 (P1), LSH2.MX2 (P1), V.MX2 (P1), X.MX2 (P1), Z.MX2 (P1); also elsewhere on the board
ROW5: MOD1A.MX2 (P1), MOD1B.MX2 (P1), MOD2A.MX2 (P1), MOD2B.MX2 (P1), MOD2C.MX1 (P0), MOD3A.MX2 (P1), MOD3B.MX2 (P1), SPACEA.MX1 (P0), SPACEB.MX2 (P1), SPACEC.MX2 (P1); also elsewhere on the board

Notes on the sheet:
Keyboard Matrix Left Half
On Double & Triple Switch Setups, Some LEDs MUST be twisted 180 For correct polarity

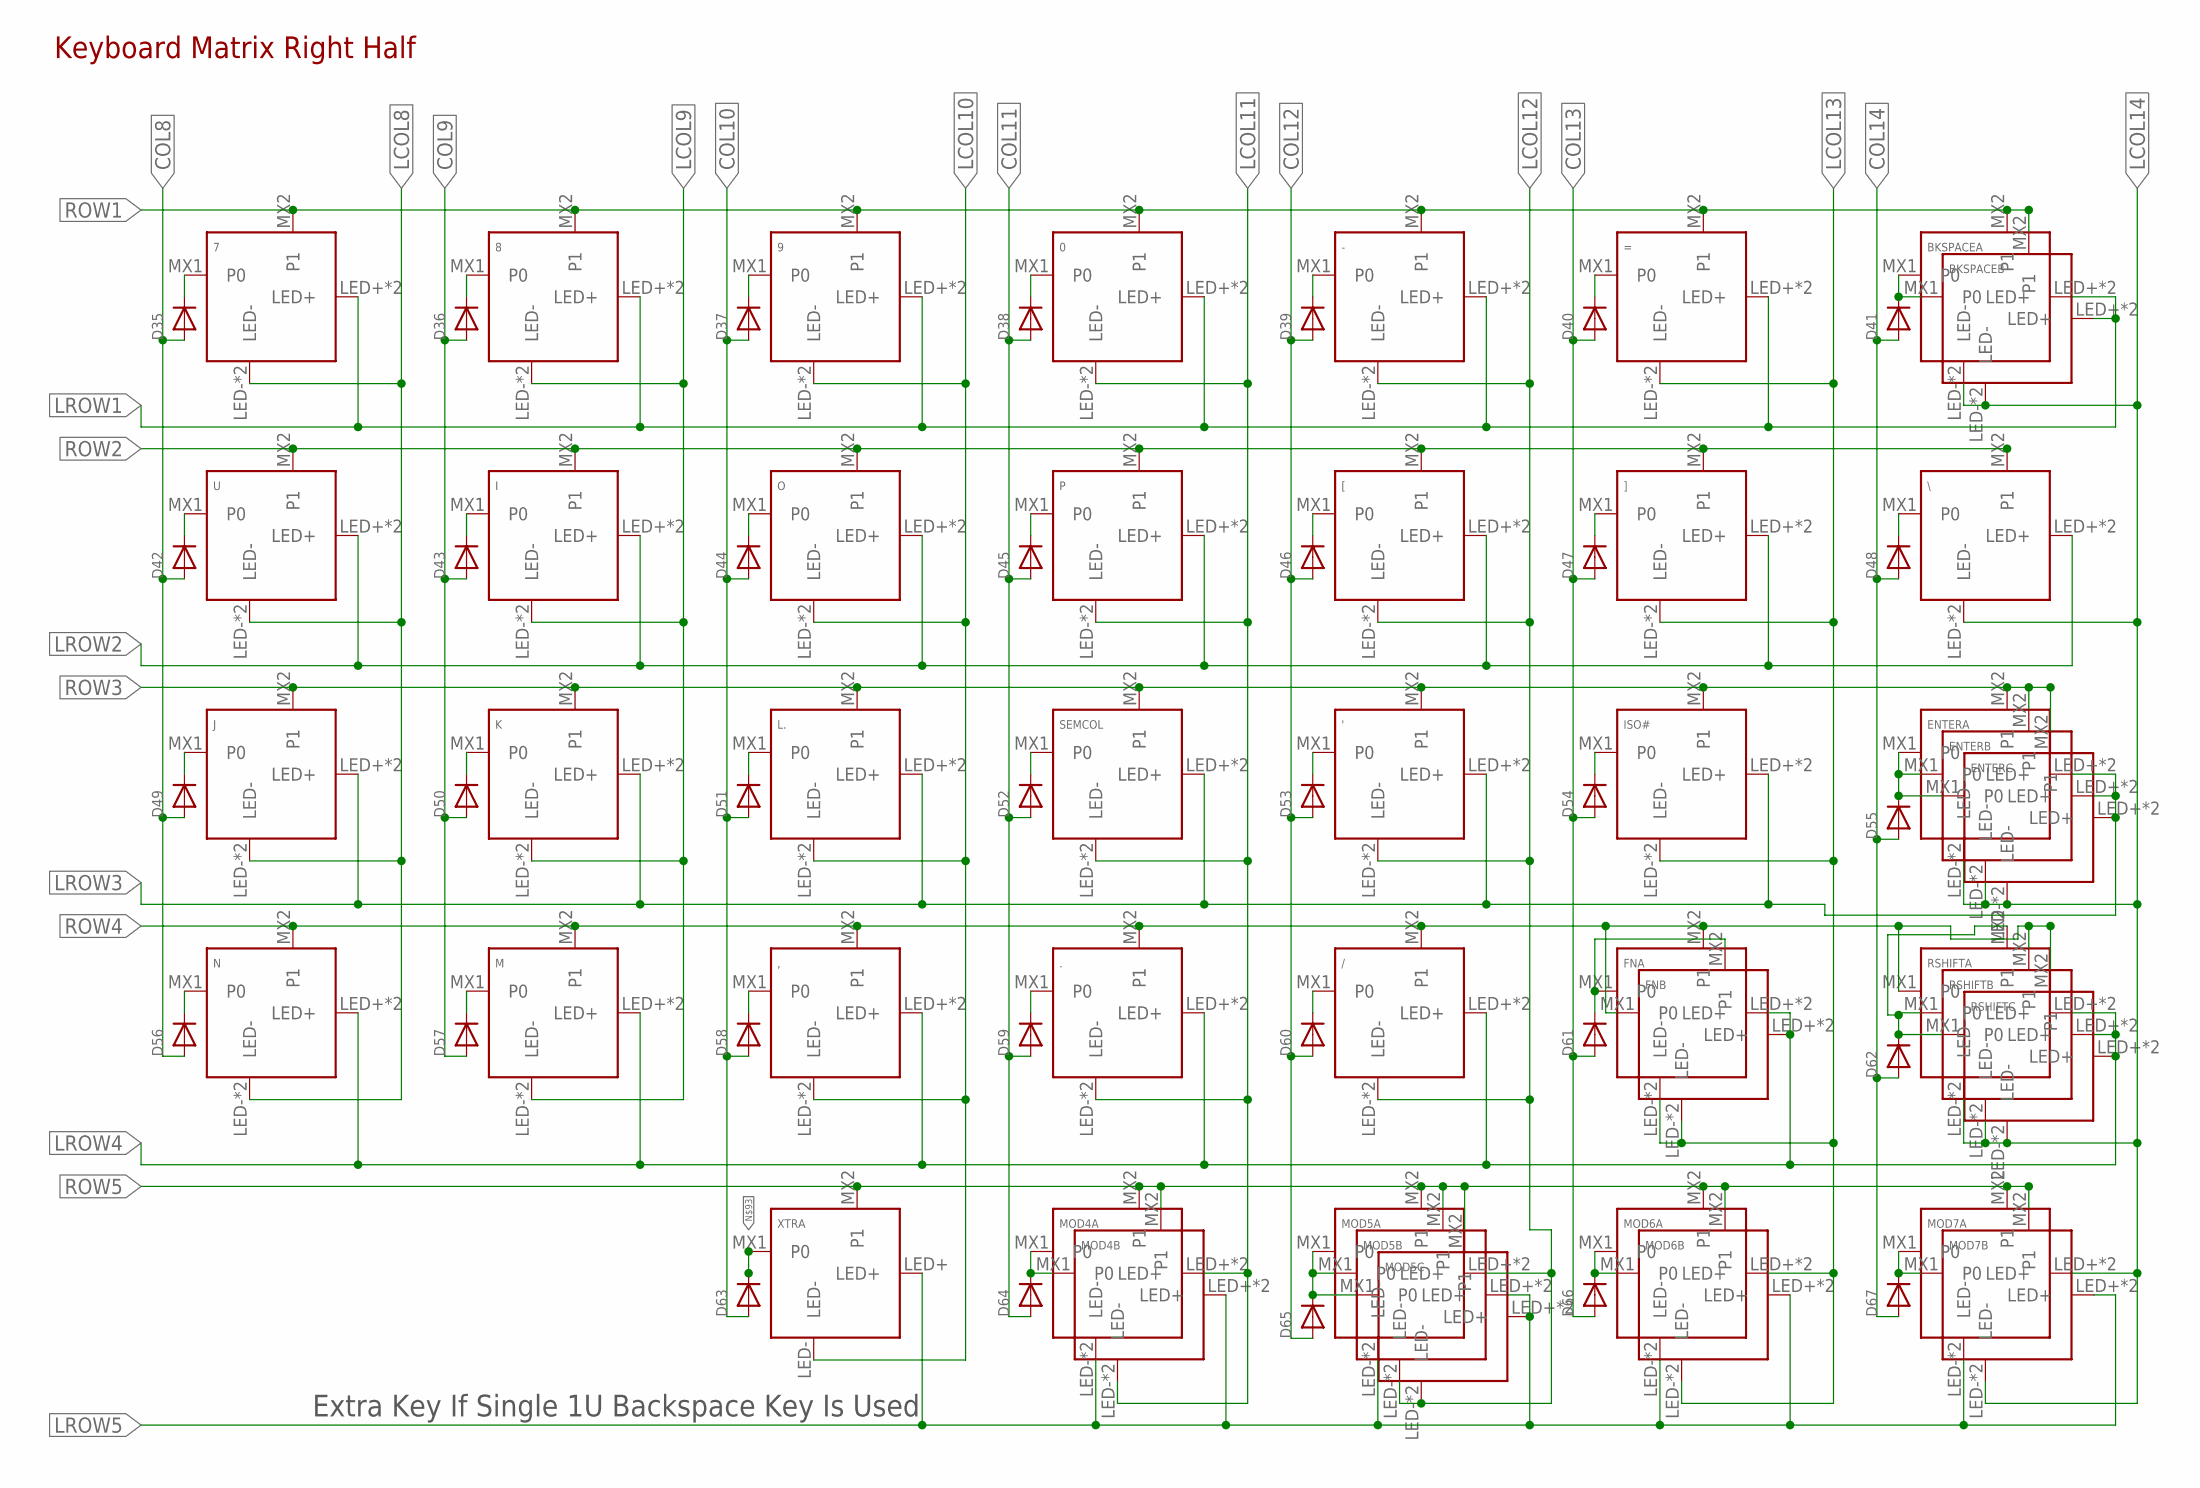
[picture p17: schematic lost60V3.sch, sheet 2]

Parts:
0, 7, 8, 9, .: KEYSWITCH-THTSMDLED-MX-1U-THTSMDLED; MX-1U-THTSMDLED
': KEYSWITCH-THTSMDLED-MX-1U-THTSMDLED; MX-1U-THTSMDLED
,: KEYSWITCH-THTSMDLED-MX-1U-THTSMDLED; MX-1U-THTSMDLED
-: KEYSWITCH-THTSMDLED-MX-1U-THTSMDLED; MX-1U-THTSMDLED
/: KEYSWITCH-THTSMDLED-MX-1U-THTSMDLED; MX-1U-THTSMDLED
=: KEYSWITCH-THTSMDLED-MX-1U-THTSMDLED; MX-1U-THTSMDLED
BKSPACEA: KEYSWITCH-THTSMDLED-MX-1U-THTSMDLED; MX-1U-THTSMDLED
BKSPACEB: KEYSWITCH-THTSMDLED-MX-2U-THTSMDLED; MX-2U-THTSMDLED
D35, D36, D37, D38, D39, D40, D41, D42, D43, D44, D45, D46, D47, D48, D49, D50, D51, D52, D53, D54, D55, D56, D57, D58, D59, D60, D61, D62, D63, D64, D65, D66, D67: DIODESOD-523; SOD-523
ENTERA: KEYSWITCH-THTSMDLED-MX-1U-THTSMDLED; MX-1U-THTSMDLED
ENTERB: KEYSWITCH-THTSMDLED-MX-2U-THTSMDLED; MX-2U-THTSMDLED
ENTERC: KEYSWITCH-THTSMDLED-MX-2U-THTSMDLED; MX-2U-THTSMDLED
FNA: KEYSWITCH-THTSMDLED-MX-1U-THTSMDLED; MX-1U-THTSMDLED
FNB: KEYSWITCH-THTSMDLED-MX-1U-THTSMDLED; MX-1U-THTSMDLED
I: KEYSWITCH-THTSMDLED-MX-1U-THTSMDLED; MX-1U-THTSMDLED
ISO#: KEYSWITCH-THTSMDLED-MX-1U-THTSMDLED; MX-1U-THTSMDLED
J: KEYSWITCH-THTSMDLED-MX-1U-THTSMDLED; MX-1U-THTSMDLED
K: KEYSWITCH-THTSMDLED-MX-1U-THTSMDLED; MX-1U-THTSMDLED
L.: KEYSWITCH-THTSMDLED-MX-1U-THTSMDLED; MX-1U-THTSMDLED
M: KEYSWITCH-THTSMDLED-MX-1U-THTSMDLED; MX-1U-THTSMDLED
MOD4A, MOD4B, MOD5A, MOD5B, MOD5C, MOD6A, MOD6B, MOD7A, MOD7B: KEYSWITCH-THTSMDLED-MX-1U-THTSMDLED; MX-1U-THTSMDLED
N: KEYSWITCH-THTSMDLED-MX-1U-THTSMDLED; MX-1U-THTSMDLED
O: KEYSWITCH-THTSMDLED-MX-1U-THTSMDLED; MX-1U-THTSMDLED
P: KEYSWITCH-THTSMDLED-MX-1U-THTSMDLED; MX-1U-THTSMDLED
RSHIFTA: KEYSWITCH-THTSMDLED-MX-1U-THTSMDLED; MX-1U-THTSMDLED
RSHIFTB: KEYSWITCH-THTSMDLED-MX-1U-THTSMDLED; MX-1U-THTSMDLED
RSHIFTC: KEYSWITCH-THTSMDLED-MX-2U-THTSMDLED; MX-2U-THTSMDLED
SEMCOL: KEYSWITCH-THTSMDLED-MX-1U-THTSMDLED; MX-1U-THTSMDLED
U: KEYSWITCH-THTSMDLED-MX-1U-THTSMDLED; MX-1U-THTSMDLED
XTRA: KEYSWITCH-THTSMDLED-MOD1; MX-1U-THTSMDLED-MOD1
[: KEYSWITCH-THTSMDLED-MX-1U-THTSMDLED; MX-1U-THTSMDLED
\: KEYSWITCH-THTSMDLED-MX-1U-THTSMDLED; MX-1U-THTSMDLED
]: KEYSWITCH-THTSMDLED-MX-1U-THTSMDLED; MX-1U-THTSMDLED

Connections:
COL8: D35.A, D42.A, D49.A, D56.A; also elsewhere on the board
COL9: D36.A, D43.A, D50.A, D57.A; also elsewhere on the board
COL10: D37.A, D44.A, D51.A, D58.A, D63.A; also elsewhere on the board
COL11: D38.A, D45.A, D52.A, D59.A, D64.A; also elsewhere on the board
COL12: D39.A, D46.A, D53.A, D60.A, D65.A; also elsewhere on the board
COL13: D40.A, D47.A, D54.A, D61.A, D66.A; also elsewhere on the board
COL14: D41.A, D48.A, D55.A, D62.A, D67.A; also elsewhere on the board
LCOL8: 7.LED-, 7.SMDLED- (LED-), J.LED-, J.SMDLED- (LED-), N.LED-, N.SMDLED- (LED-), U.LED-, U.SMDLED- (LED-); also elsewhere on the board
LCOL9: 8.LED-, 8.SMDLED- (LED-), I.LED-, I.SMDLED- (LED-), K.LED-, K.SMDLED- (LED-), M.LED-, M.SMDLED- (LED-); also elsewhere on the board
LCOL10: 9.LED-, 9.SMDLED- (LED-), ,.LED-, ,.SMDLED- (LED-), L..LED-, L..SMDLED- (LED-), O.LED-, O.SMDLED- (LED-), XTRA.LED-; also elsewhere on the board
LCOL11: 0.LED-, 0.SMDLED- (LED-), ..LED-, ..SMDLED- (LED-), MOD4A.LED+, MOD4A.SMDLED+ (LED+), MOD4B.LED-, MOD4B.SMDLED- (LED-), P.LED-, P.SMDLED- (LED-), SEMCOL.LED-, SEMCOL.SMDLED- (LED-); also elsewhere on the board
LCOL12: '.LED-, '.SMDLED- (LED-), -.LED-, -.SMDLED- (LED-), /.LED-, /.SMDLED- (LED-), MOD5A.LED+, MOD5A.SMDLED+ (LED+), MOD5B.LED-, MOD5B.SMDLED- (LED-), MOD5C.LED-, MOD5C.SMDLED- (LED-), [.LED-, [.SMDLED- (LED-); also elsewhere on the board
LCOL13: =.LED-, =.SMDLED- (LED-), FNA.LED-, FNA.SMDLED- (LED-), FNB.LED-, FNB.SMDLED- (LED-), ISO#.LED-, ISO#.SMDLED- (LED-), MOD6A.LED+, MOD6A.SMDLED+ (LED+), MOD6B.LED-, MOD6B.SMDLED- (LED-), ].LED-, ].SMDLED- (LED-); also elsewhere on the board
LCOL14: BKSPACEA.LED-, BKSPACEA.SMDLED- (LED-), BKSPACEB.LED-, BKSPACEB.SMDLED- (LED-), ENTERA.LED-, ENTERA.SMDLED- (LED-), ENTERB.LED-, ENTERB.SMDLED- (LED-), ENTERC.LED-, ENTERC.SMDLED- (LED-), MOD7A.LED+, MOD7A.SMDLED+ (LED+), MOD7B.LED-, MOD7B.SMDLED- (LED-), RSHIFTA.LED-, RSHIFTA.SMDLED- (LED-), RSHIFTB.LED-, RSHIFTB.SMDLED- (LED-), RSHIFTC.LED-, RSHIFTC.SMDLED- (LED-), \.LED-, \.SMDLED- (LED-); also elsewhere on the board
LROW1: 0.LED+, 0.SMDLED+ (LED+), 7.LED+, 7.SMDLED+ (LED+), 8.LED+, 8.SMDLED+ (LED+), 9.LED+, 9.SMDLED+ (LED+), -.LED+, -.SMDLED+ (LED+), =.LED+, =.SMDLED+ (LED+), BKSPACEA.LED+, BKSPACEA.SMDLED+ (LED+), BKSPACEB.LED+, BKSPACEB.SMDLED+ (LED+); also elsewhere on the board
LROW2: I.LED+, I.SMDLED+ (LED+), O.LED+, O.SMDLED+ (LED+), P.LED+, P.SMDLED+ (LED+), U.LED+, U.SMDLED+ (LED+), [.LED+, [.SMDLED+ (LED+), \.LED+, \.SMDLED+ (LED+), ].LED+, ].SMDLED+ (LED+); also elsewhere on the board
LROW3: '.LED+, '.SMDLED+ (LED+), ENTERA.LED+, ENTERA.SMDLED+ (LED+), ENTERB.LED+, ENTERB.SMDLED+ (LED+), ENTERC.LED+, ENTERC.SMDLED+ (LED+), ISO#.LED+, ISO#.SMDLED+ (LED+), J.LED+, J.SMDLED+ (LED+), K.LED+, K.SMDLED+ (LED+), L..LED+, L..SMDLED+ (LED+), SEMCOL.LED+, SEMCOL.SMDLED+ (LED+); also elsewhere on the board
LROW4: ,.LED+, ,.SMDLED+ (LED+), ..LED+, ..SMDLED+ (LED+), /.LED+, /.SMDLED+ (LED+), FNA.LED+, FNA.SMDLED+ (LED+), FNB.LED+, FNB.SMDLED+ (LED+), M.LED+, M.SMDLED+ (LED+), N.LED+, N.SMDLED+ (LED+), RSHIFTA.LED+, RSHIFTA.SMDLED+ (LED+), RSHIFTB.LED+, RSHIFTB.SMDLED+ (LED+), RSHIFTC.LED+, RSHIFTC.SMDLED+ (LED+); also elsewhere on the board
LROW5: MOD4A.LED-, MOD4A.SMDLED- (LED-), MOD4B.LED+, MOD4B.SMDLED+ (LED+), MOD5A.LED-, MOD5A.SMDLED- (LED-), MOD5B.LED+, MOD5B.SMDLED+ (LED+), MOD5C.LED+, MOD5C.SMDLED+ (LED+), MOD6A.LED-, MOD6A.SMDLED- (LED-), MOD6B.LED+, MOD6B.SMDLED+ (LED+), MOD7A.LED-, MOD7A.SMDLED- (LED-), MOD7B.LED+, MOD7B.SMDLED+ (LED+), XTRA.LED+; also elsewhere on the board
unnamed: 7.MX1 (P0), D35.K (C)
unnamed: D62.K (C), RSHIFTA.MX2 (P1), RSHIFTB.MX1 (P0), RSHIFTC.MX1 (P0)
unnamed: 8.MX1 (P0), D36.K (C)
unnamed: 9.MX1 (P0), D37.K (C)
unnamed: 0.MX1 (P0), D38.K (C)
unnamed: -.MX1 (P0), D39.K (C)
unnamed: =.MX1 (P0), D40.K (C)
unnamed: BKSPACEA.MX1 (P0), BKSPACEB.MX1 (P0), D41.K (C)
unnamed: D42.K (C), U.MX1 (P0)
unnamed: D43.K (C), I.MX1 (P0)
unnamed: D44.K (C), O.MX1 (P0)
unnamed: D45.K (C), P.MX1 (P0)
unnamed: D46.K (C), [.MX1 (P0)
unnamed: D47.K (C), ].MX1 (P0)
unnamed: D48.K (C), \.MX1 (P0)
unnamed: D49.K (C), J.MX1 (P0)
unnamed: D50.K (C), K.MX1 (P0)
unnamed: D51.K (C), L..MX1 (P0)
unnamed: D52.K (C), SEMCOL.MX1 (P0)
unnamed: '.MX1 (P0), D53.K (C)
unnamed: D54.K (C), ISO#.MX1 (P0)
unnamed: D55.K (C), ENTERA.MX1 (P0), ENTERB.MX1 (P0), ENTERC.MX1 (P0)
unnamed: D56.K (C), N.MX1 (P0)
unnamed: D57.K (C), M.MX1 (P0)
unnamed: ,.MX1 (P0), D58.K (C)
unnamed: ..MX1 (P0), D59.K (C)
unnamed: /.MX1 (P0), D60.K (C)
unnamed: D61.K (C), FNA.MX1 (P0), FNB.MX2 (P1)
unnamed 147: D63.K (C), XTRA.MX1 (P0); also elsewhere on the board
unnamed: D64.K (C), MOD4A.MX1 (P0), MOD4B.MX1 (P0)
unnamed: D65.K (C), MOD5A.MX1 (P0), MOD5B.MX1 (P0), MOD5C.MX1 (P0)
unnamed: D66.K (C), MOD6A.MX1 (P0), MOD6B.MX1 (P0)
unnamed: D67.K (C), MOD7A.MX1 (P0), MOD7B.MX1 (P0)
ROW1: 0.MX2 (P1), 7.MX2 (P1), 8.MX2 (P1), 9.MX2 (P1), -.MX2 (P1), =.MX2 (P1), BKSPACEA.MX2 (P1), BKSPACEB.MX2 (P1); also elsewhere on the board
ROW2: I.MX2 (P1), O.MX2 (P1), P.MX2 (P1), U.MX2 (P1), [.MX2 (P1), \.MX2 (P1), ].MX2 (P1); also elsewhere on the board
ROW3: '.MX2 (P1), ENTERA.MX2 (P1), ENTERB.MX2 (P1), ENTERC.MX2 (P1), ISO#.MX2 (P1), J.MX2 (P1), K.MX2 (P1), L..MX2 (P1), SEMCOL.MX2 (P1); also elsewhere on the board
ROW4: ,.MX2 (P1), ..MX2 (P1), /.MX2 (P1), FNA.MX2 (P1), FNB.MX1 (P0), M.MX2 (P1), N.MX2 (P1), RSHIFTA.MX1 (P0), RSHIFTB.MX2 (P1), RSHIFTC.MX2 (P1); also elsewhere on the board
ROW5: MOD4A.MX2 (P1), MOD4B.MX2 (P1), MOD5A.MX2 (P1), MOD5B.MX2 (P1), MOD5C.MX2 (P1), MOD6A.MX2 (P1), MOD6B.MX2 (P1), MOD7A.MX2 (P1), MOD7B.MX2 (P1), XTRA.MX2 (P1); also elsewhere on the board

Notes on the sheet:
Extra Key If Single 1U Backspace Key Is Used
Keyboard Matrix Right Half

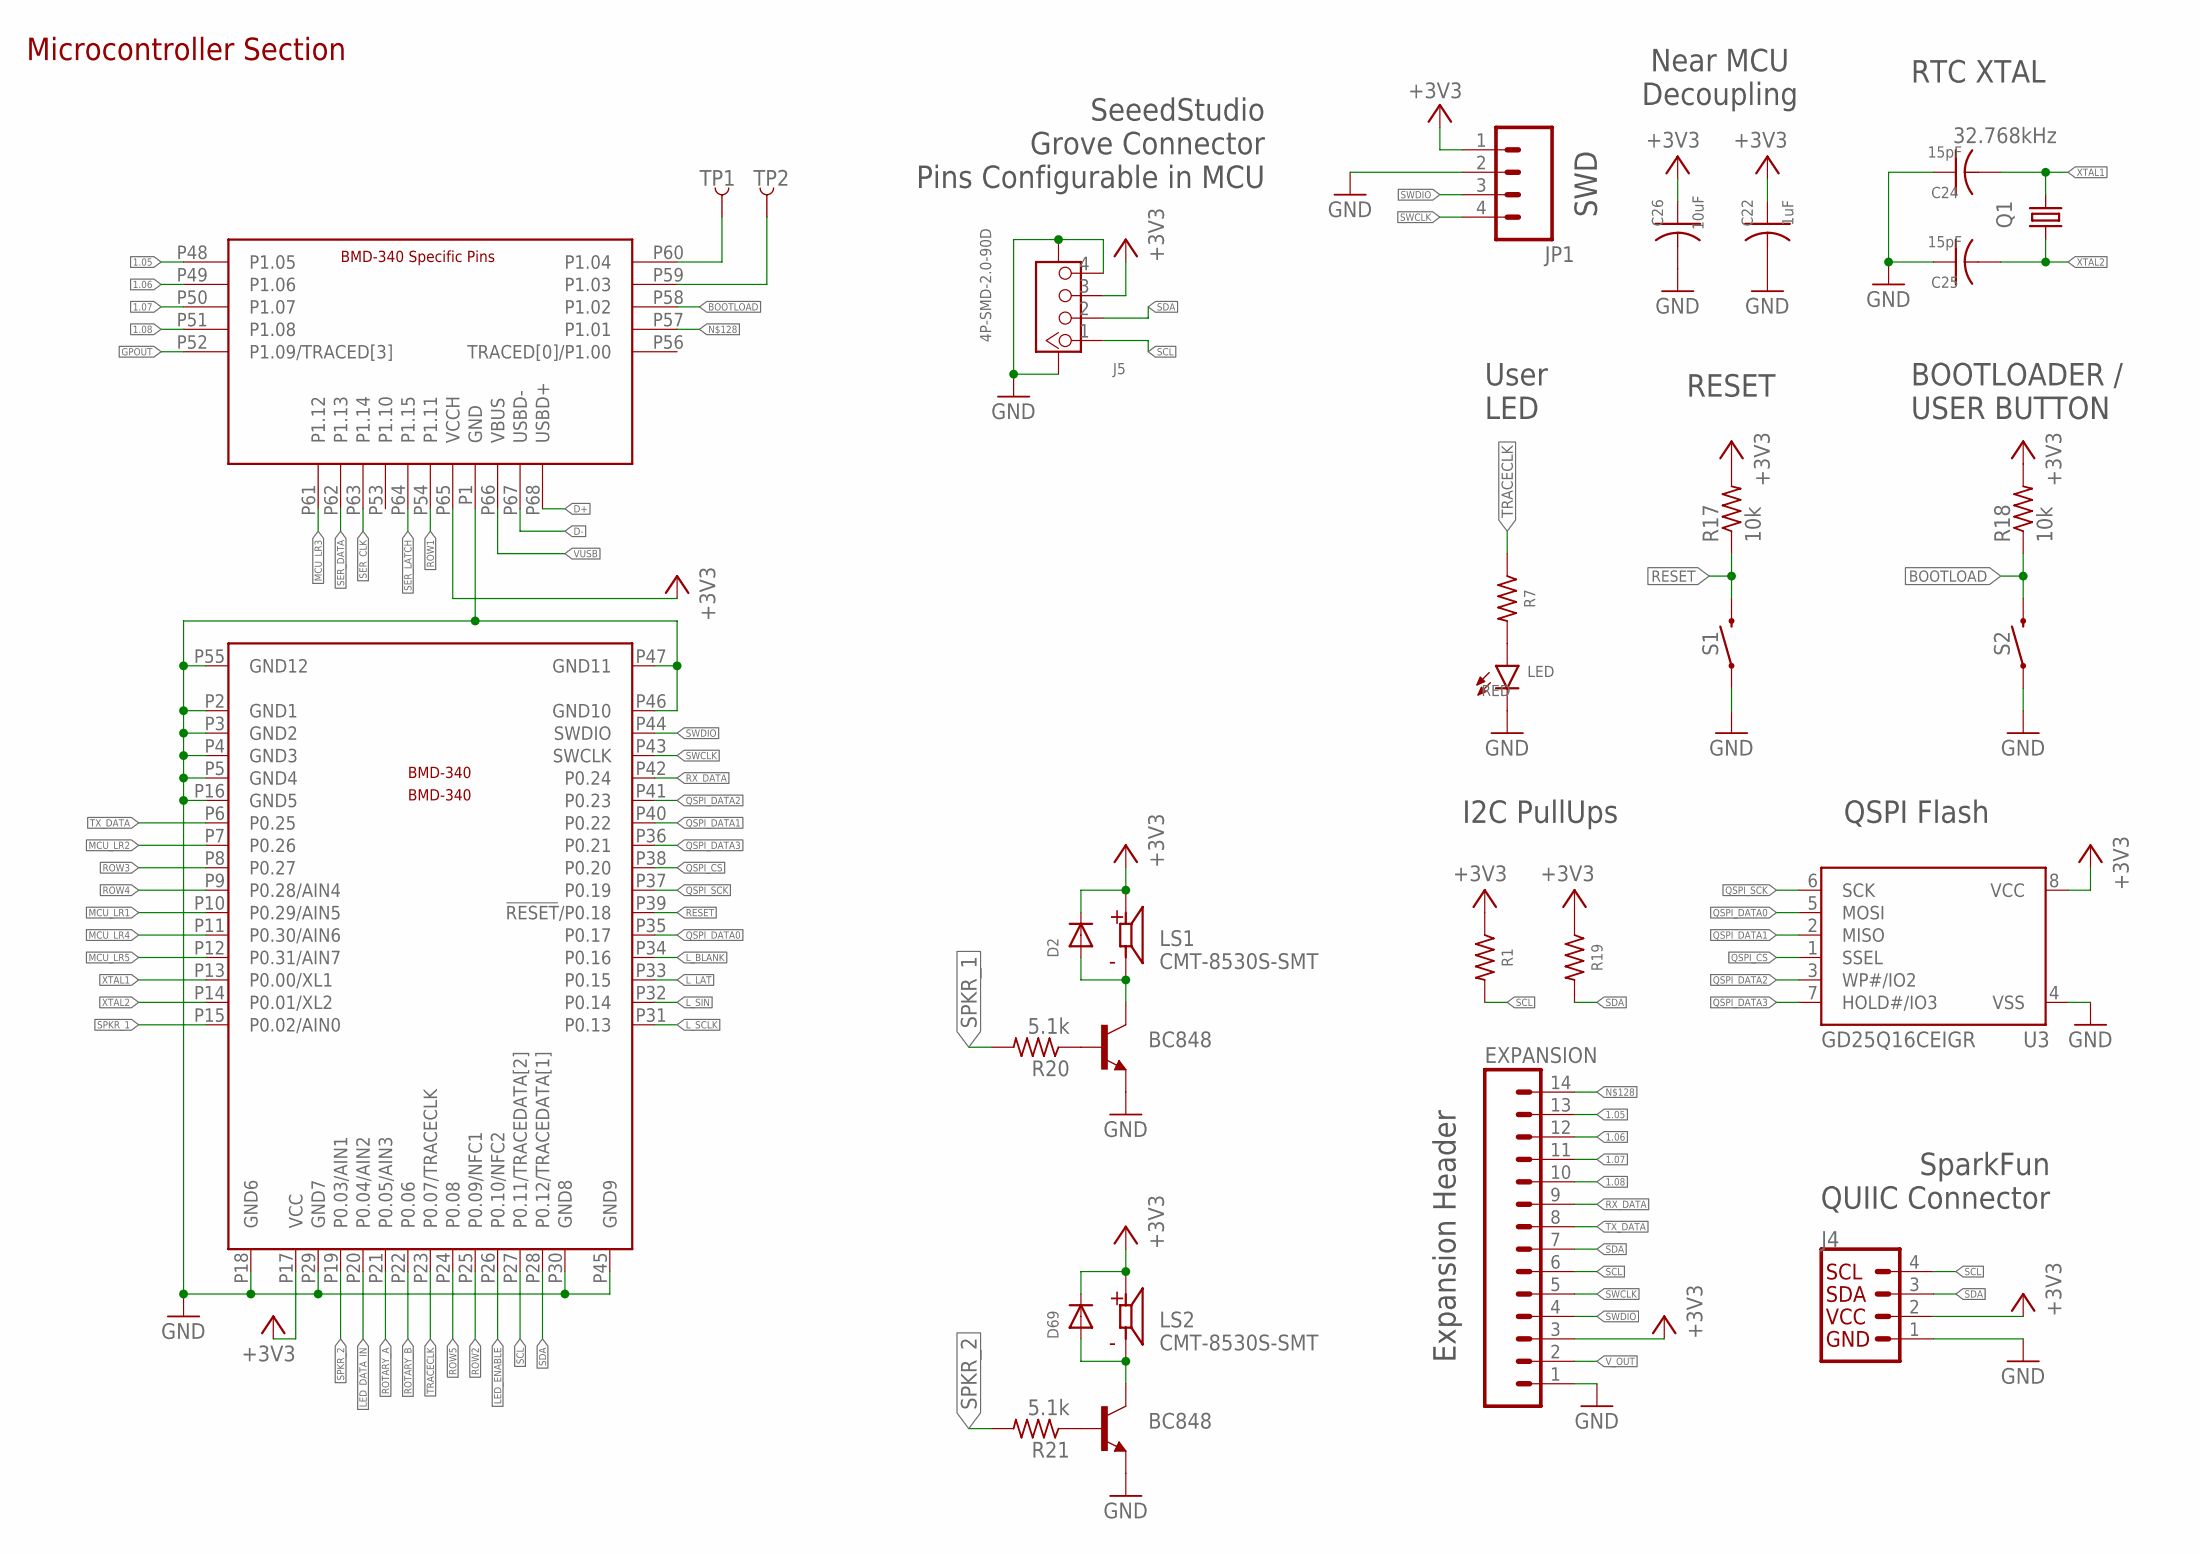
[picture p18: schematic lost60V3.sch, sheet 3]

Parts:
BMD-340: BMD-340
C22: 1uF; C0603K
C24, C25: 15pF; C0603K
C26: 10uF; C0603K
D2, D69: DIODESOD-523; SOD-523
EXPANSION: M14; 1X14
J4: QWIIC_CONNECTORJS-1MM; 1X04_1MM_RA
J5: 4P-SMD-2.0-90D; HW4-SMD-2.0-90D
JP1: M04PTH; 1X04
LED: RED; LED-0603
LS1, LS2: CMT-8530S-SMT; CUI_CMT-8530S-SMT
Q1: 32.768kHz; 3.2X1.5
R1, R7, R19: 1k; R0603
R17, R18: 10k; R0603
R20, R21: 5.1k; R0603
S1, S2: MOMENTARY-SWITCH-SPST-SMD-4.6X2.8MM; TACTILE_SWITCH_SMD_4.6X2.8MM
T6, T7: BC848; SOT23
TP1, TP2: TEST-POINT3X5; PAD.03X.05
U3: GD25Q16CEIGR; MICROBUILDER_USON8

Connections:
1.05: BMD-340.P48 (P1.05), EXPANSION.13
1.06: BMD-340.P49 (P1.06), EXPANSION.12
1.07: BMD-340.P50 (P1.07), EXPANSION.11
1.08: BMD-340.P51 (P1.08), EXPANSION.10
+3V1: D2.A, LS1.N, T6.3 (C)
+3V2: D69.A, LS2.N, T7.3 (C)
+3V3: BMD-340.P17 (VCC), BMD-340.P65 (VCCH), C22.1, C26.1, D2.K (C), D69.K (C), EXPANSION.3, J4.2 (VCC), J5.3, JP1.1, LS1.P, LS2.P, R1.1, R17.2, R18.2, R19.1, U3.8 (VCC); also elsewhere on the board
BOOTLOAD: BMD-340.P58 (P1.02), R18.1, S2.3 (2), S2.4 (2)
D+: BMD-340.P68 (USBD+); also elsewhere on the board
D-: BMD-340.P67 (USBD-); also elsewhere on the board
GND: BMD-340.P1 (GND), BMD-340.P2 (GND1), BMD-340.P3 (GND2), BMD-340.P4 (GND3), BMD-340.P5 (GND4), BMD-340.P16 (GND5), BMD-340.P18 (GND6), BMD-340.P29 (GND7), BMD-340.P30 (GND8), BMD-340.P45 (GND9), BMD-340.P46 (GND10), BMD-340.P47 (GND11), BMD-340.P55 (GND12), C22.2, C24.1, C25.1, C26.2, EXPANSION.1, J4.1 (GND), J5.4, J5.SS1, J5.SS2, JP1.2, LED.C, S1.1, S1.2 (1), S2.1, S2.2 (1), T6.2 (E), T7.2 (E), U3.4 (VSS); also elsewhere on the board
GPOUT: BMD-340.P52 (P1.09/TRACED[3]); also elsewhere on the board
LED_DATA_IN: BMD-340.P20 (P0.04/AIN2); also elsewhere on the board
LED_ENABLE: BMD-340.P26 (P0.10/NFC2); also elsewhere on the board
L_BLANK: BMD-340.P34 (P0.16); also elsewhere on the board
L_LAT: BMD-340.P33 (P0.15); also elsewhere on the board
L_SCLK: BMD-340.P31 (P0.13); also elsewhere on the board
L_SIN: BMD-340.P32 (P0.14); also elsewhere on the board
MCU_LR1: BMD-340.P10 (P0.29/AIN5); also elsewhere on the board
MCU_LR2: BMD-340.P7 (P0.26); also elsewhere on the board
MCU_LR3: BMD-340.P61 (P1.12); also elsewhere on the board
MCU_LR4: BMD-340.P11 (P0.30/AIN6); also elsewhere on the board
MCU_LR5: BMD-340.P12 (P0.31/AIN7); also elsewhere on the board
unnamed: LED.A, R7.2
unnamed: R20.1, T6.1 (B)
unnamed: R21.1, T7.1 (B)
unnamed: BMD-340.P57 (P1.01), EXPANSION.14
unnamed: BMD-340.P59 (P1.03), TP2.P$1
unnamed: BMD-340.P60 (P1.04), TP1.P$1
QSPI_CS: BMD-340.P38 (P0.20), U3.1 (SSEL)
QSPI_DATA0: BMD-340.P35 (P0.17), U3.5 (MOSI)
QSPI_DATA1: BMD-340.P40 (P0.22), U3.2 (MISO)
QSPI_DATA2: BMD-340.P41 (P0.23), U3.3 (WP#/IO2)
QSPI_DATA3: BMD-340.P36 (P0.21), U3.7 (HOLD#/IO3)
QSPI_SCK: BMD-340.P37 (P0.19), U3.6 (SCK)
RESET: BMD-340.P39 (!RESET!/P0.18), R17.1, S1.3 (2), S1.4 (2)
ROTARY_A: BMD-340.P21 (P0.05/AIN3); also elsewhere on the board
ROTARY_B: BMD-340.P22 (P0.06); also elsewhere on the board
ROW1: BMD-340.P54 (P1.11); also elsewhere on the board
ROW2: BMD-340.P25 (P0.09/NFC1); also elsewhere on the board
ROW3: BMD-340.P8 (P0.27); also elsewhere on the board
ROW4: BMD-340.P9 (P0.28/AIN4); also elsewhere on the board
ROW5: BMD-340.P24 (P0.08); also elsewhere on the board
RX_DATA: BMD-340.P42 (P0.24), EXPANSION.9
SCL: BMD-340.P27 (P0.11/TRACEDATA[2]), EXPANSION.6, J4.4 (SCL), J5.1, R1.2; also elsewhere on the board
SDA: BMD-340.P28 (P0.12/TRACEDATA[1]), EXPANSION.7, J4.3 (SDA), J5.2, R19.2; also elsewhere on the board
SER_CLK: BMD-340.P63 (P1.14); also elsewhere on the board
SER_DATA: BMD-340.P62 (P1.13); also elsewhere on the board
SER_LATCH: BMD-340.P64 (P1.15); also elsewhere on the board
SPKR_1: BMD-340.P15 (P0.02/AIN0), R20.2
SPKR_2: BMD-340.P19 (P0.03/AIN1), R21.2
SWCLK: BMD-340.P43 (SWCLK), EXPANSION.5, JP1.4
SWDIO: BMD-340.P44 (SWDIO), EXPANSION.4, JP1.3
TRACECLK: BMD-340.P23 (P0.07/TRACECLK), R7.1
TX_DATA: BMD-340.P6 (P0.25), EXPANSION.8
VUSB: BMD-340.P66 (VBUS); also elsewhere on the board
V_OUT: EXPANSION.2; also elsewhere on the board
XTAL1: BMD-340.P13 (P0.00/XL1), C24.2, Q1.2
XTAL2: BMD-340.P14 (P0.01/XL2), C25.2, Q1.1

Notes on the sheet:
SWD
Microcontroller Section
Near MCU Decoupling
RTC XTAL
User LED
RESET
BOOTLOADER / USER BUTTON
I2C PullUps
QSPI Flash
SparkFun QUIIC Connector
Expansion Header
SeeedStudio Grove Connector Pins Configurable in MCU

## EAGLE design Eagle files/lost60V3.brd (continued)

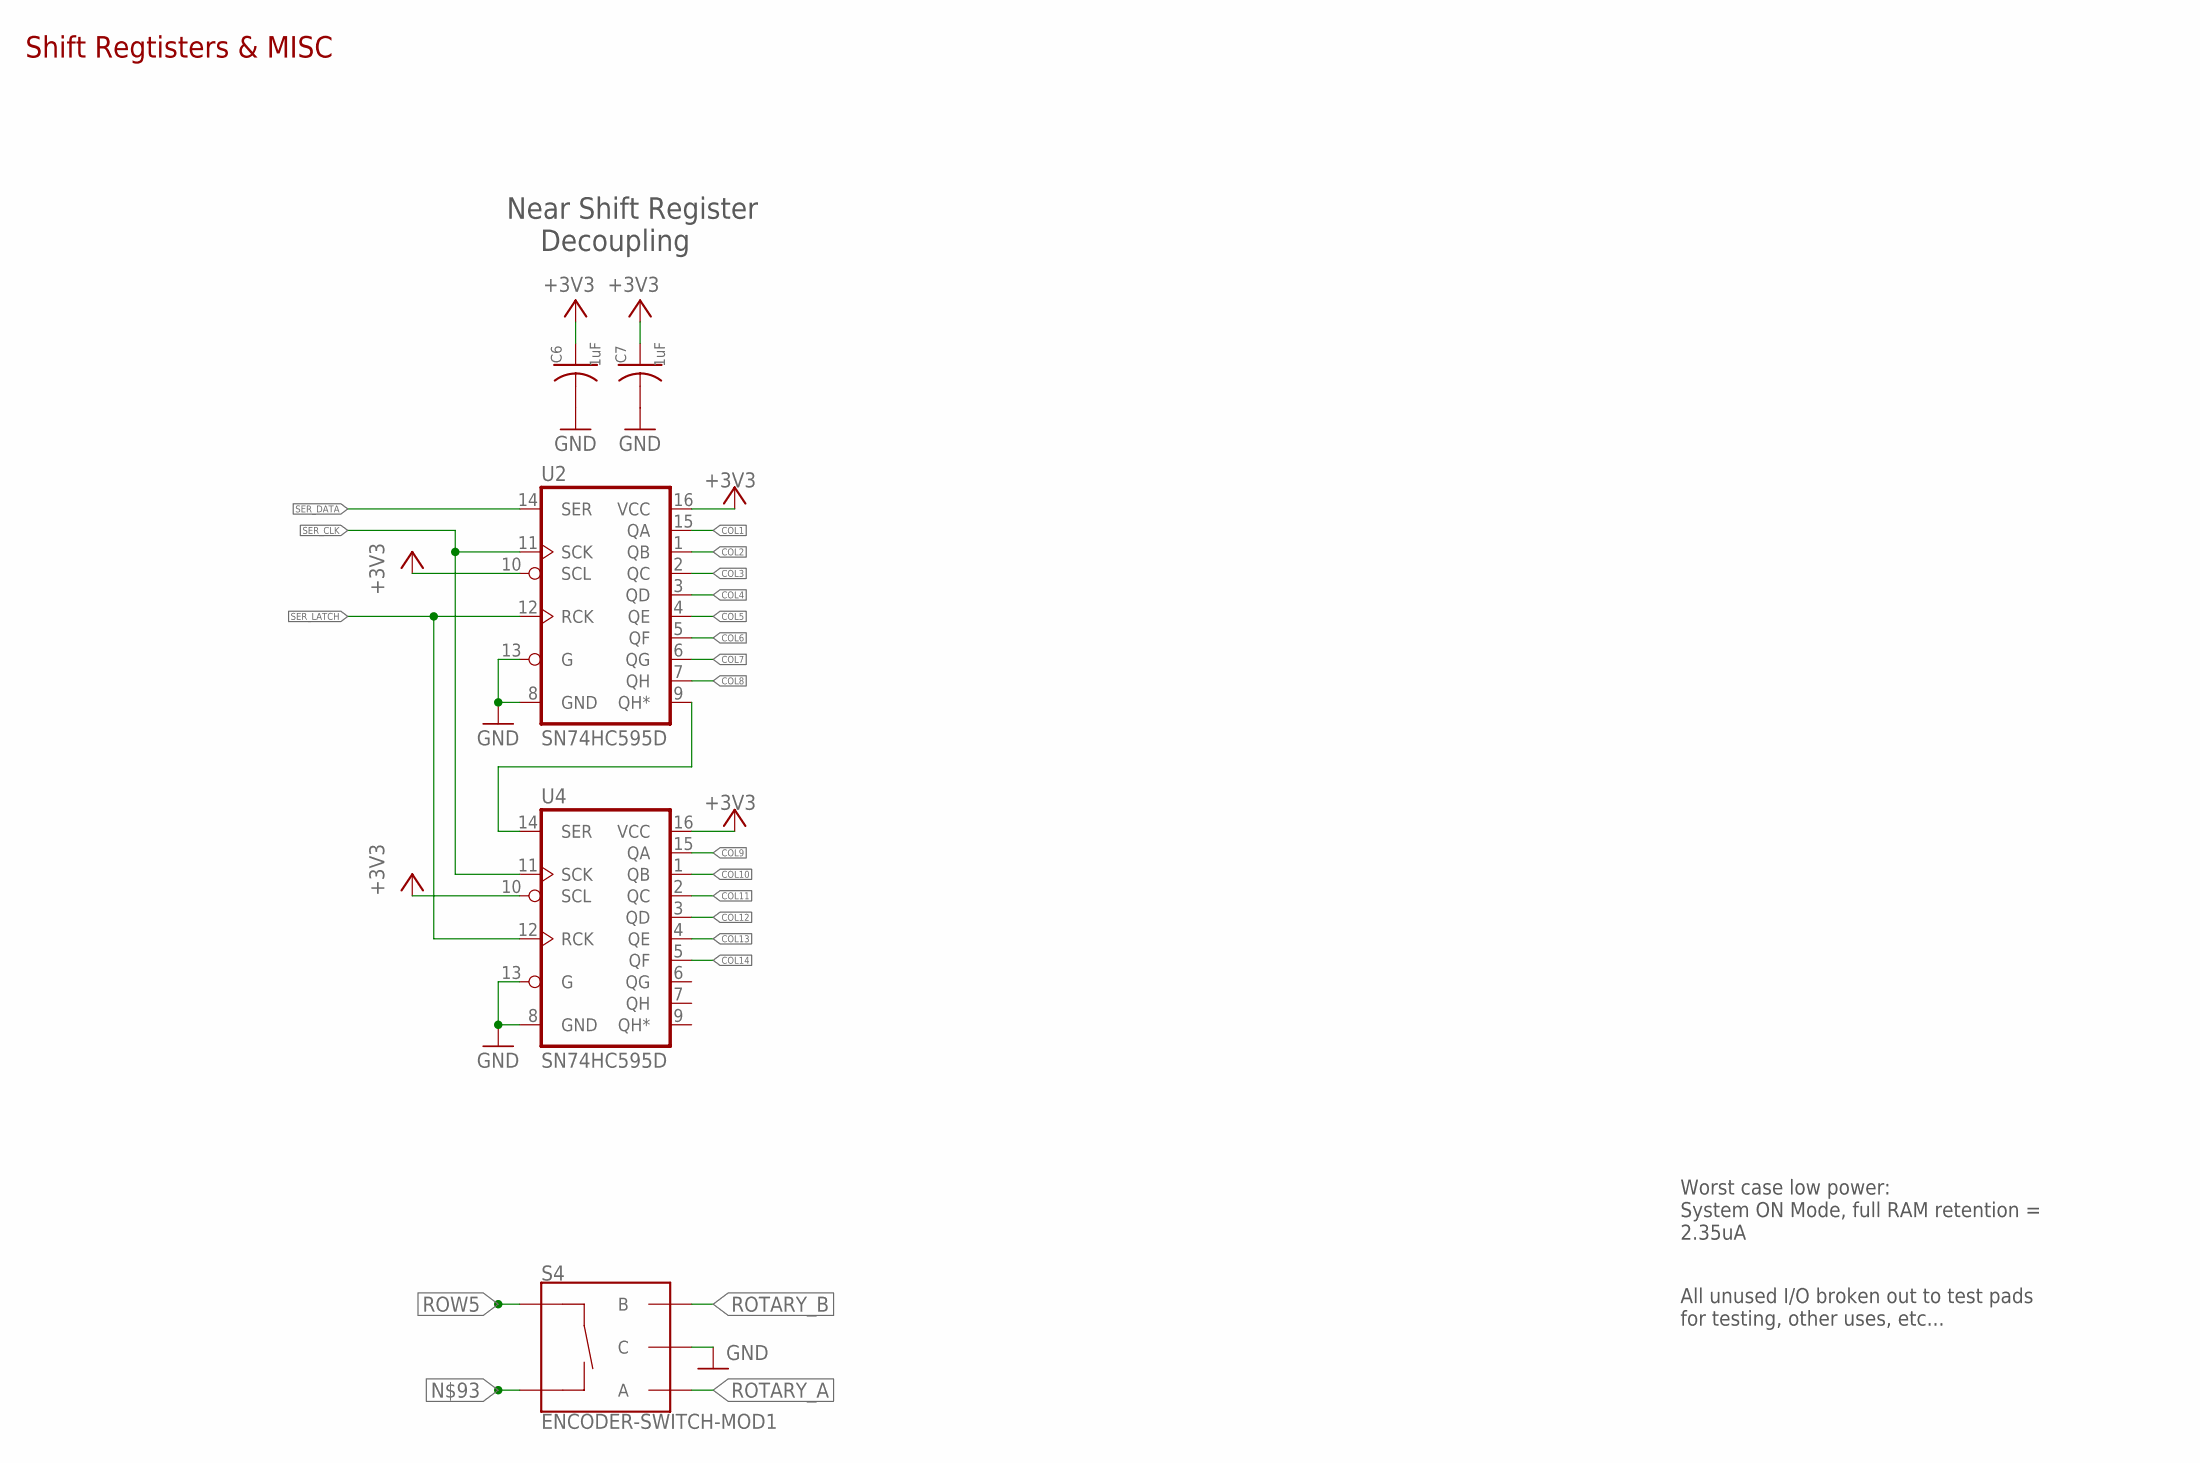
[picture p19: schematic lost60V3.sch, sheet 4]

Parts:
C6, C7: 1uF; C0603K
S4: ENCODER-SWITCH-MOD1; ROTARY_ENC_PLAIN-MOD1
U2, U4: SN74HC595D; SO16

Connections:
+3V3: C6.1, C7.1, U2.10 (SCL), U2.16 (VCC), U4.10 (SCL), U4.16 (VCC); also elsewhere on the board
COL1: U2.15 (QA); also elsewhere on the board
COL2: U2.1 (QB); also elsewhere on the board
COL3: U2.2 (QC); also elsewhere on the board
COL4: U2.3 (QD); also elsewhere on the board
COL5: U2.4 (QE); also elsewhere on the board
COL6: U2.5 (QF); also elsewhere on the board
COL7: U2.6 (QG); also elsewhere on the board
COL8: U2.7 (QH); also elsewhere on the board
COL9: U4.15 (QA); also elsewhere on the board
COL10: U4.1 (QB); also elsewhere on the board
COL11: U4.2 (QC); also elsewhere on the board
COL12: U4.3 (QD); also elsewhere on the board
COL13: U4.4 (QE); also elsewhere on the board
COL14: U4.5 (QF); also elsewhere on the board
GND: C6.2, C7.2, S4.C, U2.8 (GND), U2.13 (G), U4.8 (GND), U4.13 (G); also elsewhere on the board
unnamed: U2.9 (QH*), U4.14 (SER)
unnamed 147: S4.SW-; also elsewhere on the board
ROTARY_A: S4.A; also elsewhere on the board
ROTARY_B: S4.B; also elsewhere on the board
ROW5: S4.SW+; also elsewhere on the board
SER_CLK: U2.11 (SCK), U4.11 (SCK); also elsewhere on the board
SER_DATA: U2.14 (SER); also elsewhere on the board
SER_LATCH: U2.12 (RCK), U4.12 (RCK); also elsewhere on the board

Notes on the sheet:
Shift Regtisters & MISC
All unused I/O broken out to test pads for testing, other uses, etc...
Worst case low power: System ON Mode, full RAM retention = 2.35uA
Near Shift Register Decoupling

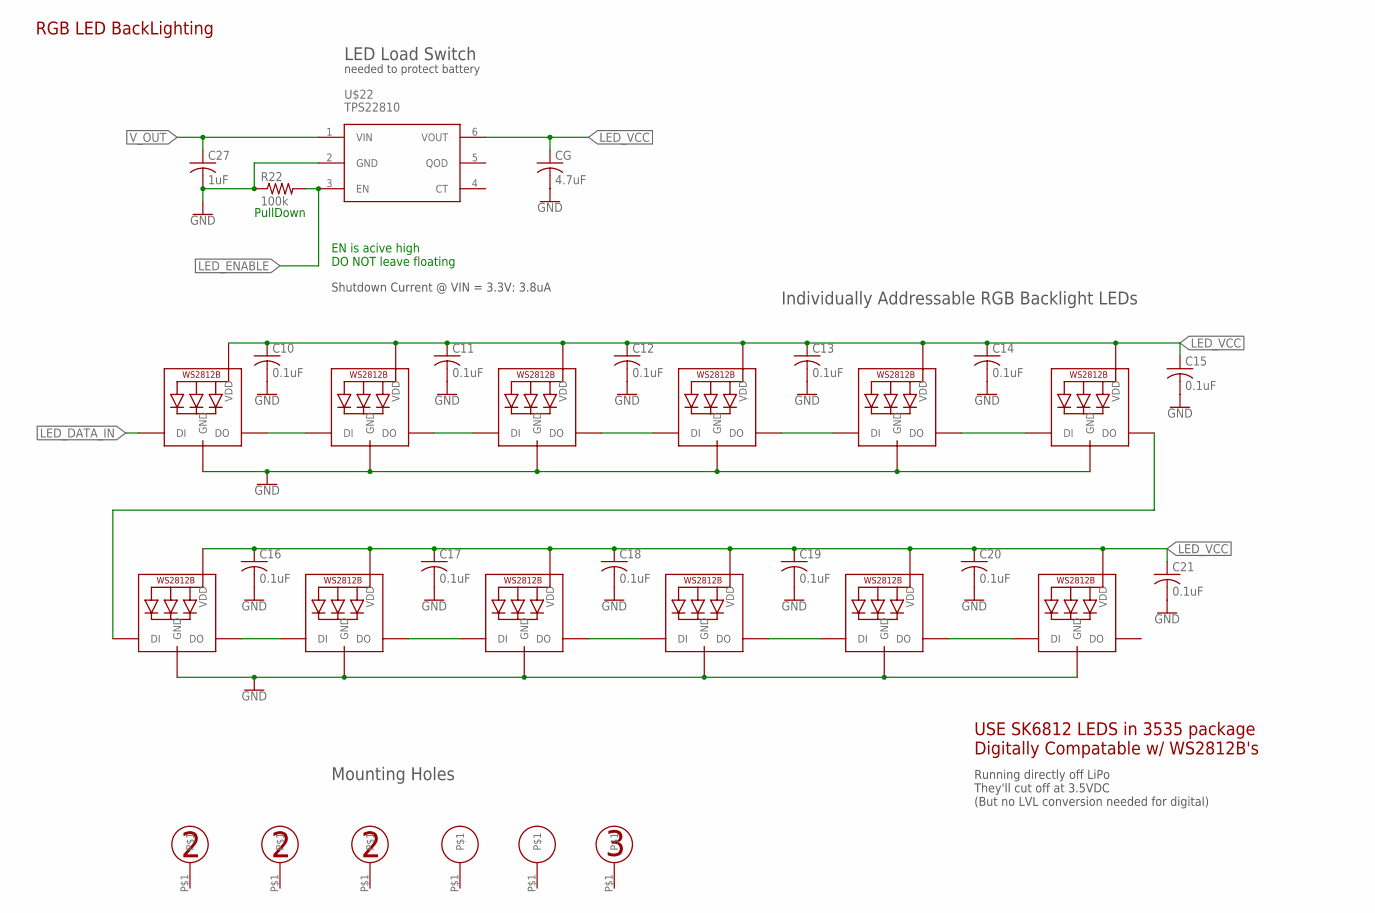
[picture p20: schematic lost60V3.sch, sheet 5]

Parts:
C10, C11, C12, C13, C14, C15, C16, C17, C18, C19, C20, C21: 0.1uF; C0603K
C27: 1uF; C0603
CG: 4.7uF; C0603
GND: GH60HOLETYPE3
LED1, LED2, LED3, LED4, LED5, LED6, LED7, LED8, LED9, LED10, LED11, LED12: WS2812B3535; LED3535
R22: 100k; R0603
U$22: TPS22810; SOT23-6
U$125, U$126: GH60HOLE
U$130, U$131, U$132: GH60HOLETYPE2

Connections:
GND: C10.2, C11.2, C12.2, C13.2, C14.2, C15.2, C16.2, C17.2, C18.2, C19.2, C20.2, C21.2, C27.2, CG.2, LED1.4 (GND), LED2.4 (GND), LED3.4 (GND), LED4.4 (GND), LED5.4 (GND), LED6.4 (GND), LED7.4 (GND), LED8.4 (GND), LED9.4 (GND), LED10.4 (GND), LED11.4 (GND), LED12.4 (GND), R22.1, U$22.2 (GND); also elsewhere on the board
LED_DATA_IN: LED4.1 (DI); also elsewhere on the board
LED_ENABLE: R22.2, U$22.3 (EN); also elsewhere on the board
LED_VCC: C10.1, C11.1, C12.1, C13.1, C14.1, C15.1, C16.1, C17.1, C18.1, C19.1, C20.1, C21.1, CG.1, LED1.2 (VDD), LED2.2 (VDD), LED3.2 (VDD), LED4.2 (VDD), LED5.2 (VDD), LED6.2 (VDD), LED7.2 (VDD), LED8.2 (VDD), LED9.2 (VDD), LED10.2 (VDD), LED11.2 (VDD), LED12.2 (VDD), U$22.6 (VOUT)
unnamed: LED1.1 (DI), LED4.3 (DO)
unnamed: LED1.3 (DO), LED3.1 (DI)
unnamed: LED2.1 (DI), LED3.3 (DO)
unnamed: LED2.3 (DO), LED5.1 (DI)
unnamed: LED5.3 (DO), LED6.1 (DI)
unnamed: LED6.3 (DO), LED7.1 (DI)
unnamed: LED7.3 (DO), LED8.1 (DI)
unnamed: LED8.3 (DO), LED9.1 (DI)
unnamed: LED9.3 (DO), LED10.1 (DI)
unnamed: LED10.3 (DO), LED11.1 (DI)
unnamed: LED11.3 (DO), LED12.1 (DI)
V_OUT: C27.1, U$22.1 (VIN); also elsewhere on the board

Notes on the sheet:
USE SK6812 LEDS in 3535 package Digitally Compatable w/ WS2812B's
Running directly off LiPo They'll cut off at 3.5VDC (But no LVL conversion needed for digital)
Mounting Holes
RGB LED BackLighting
Individually Addressable RGB Backlight LEDs
EN is acive high DO NOT leave floating
PullDown
LED Load Switch
needed to protect battery
Shutdown Current @ VIN = 3.3V: 3.8uA

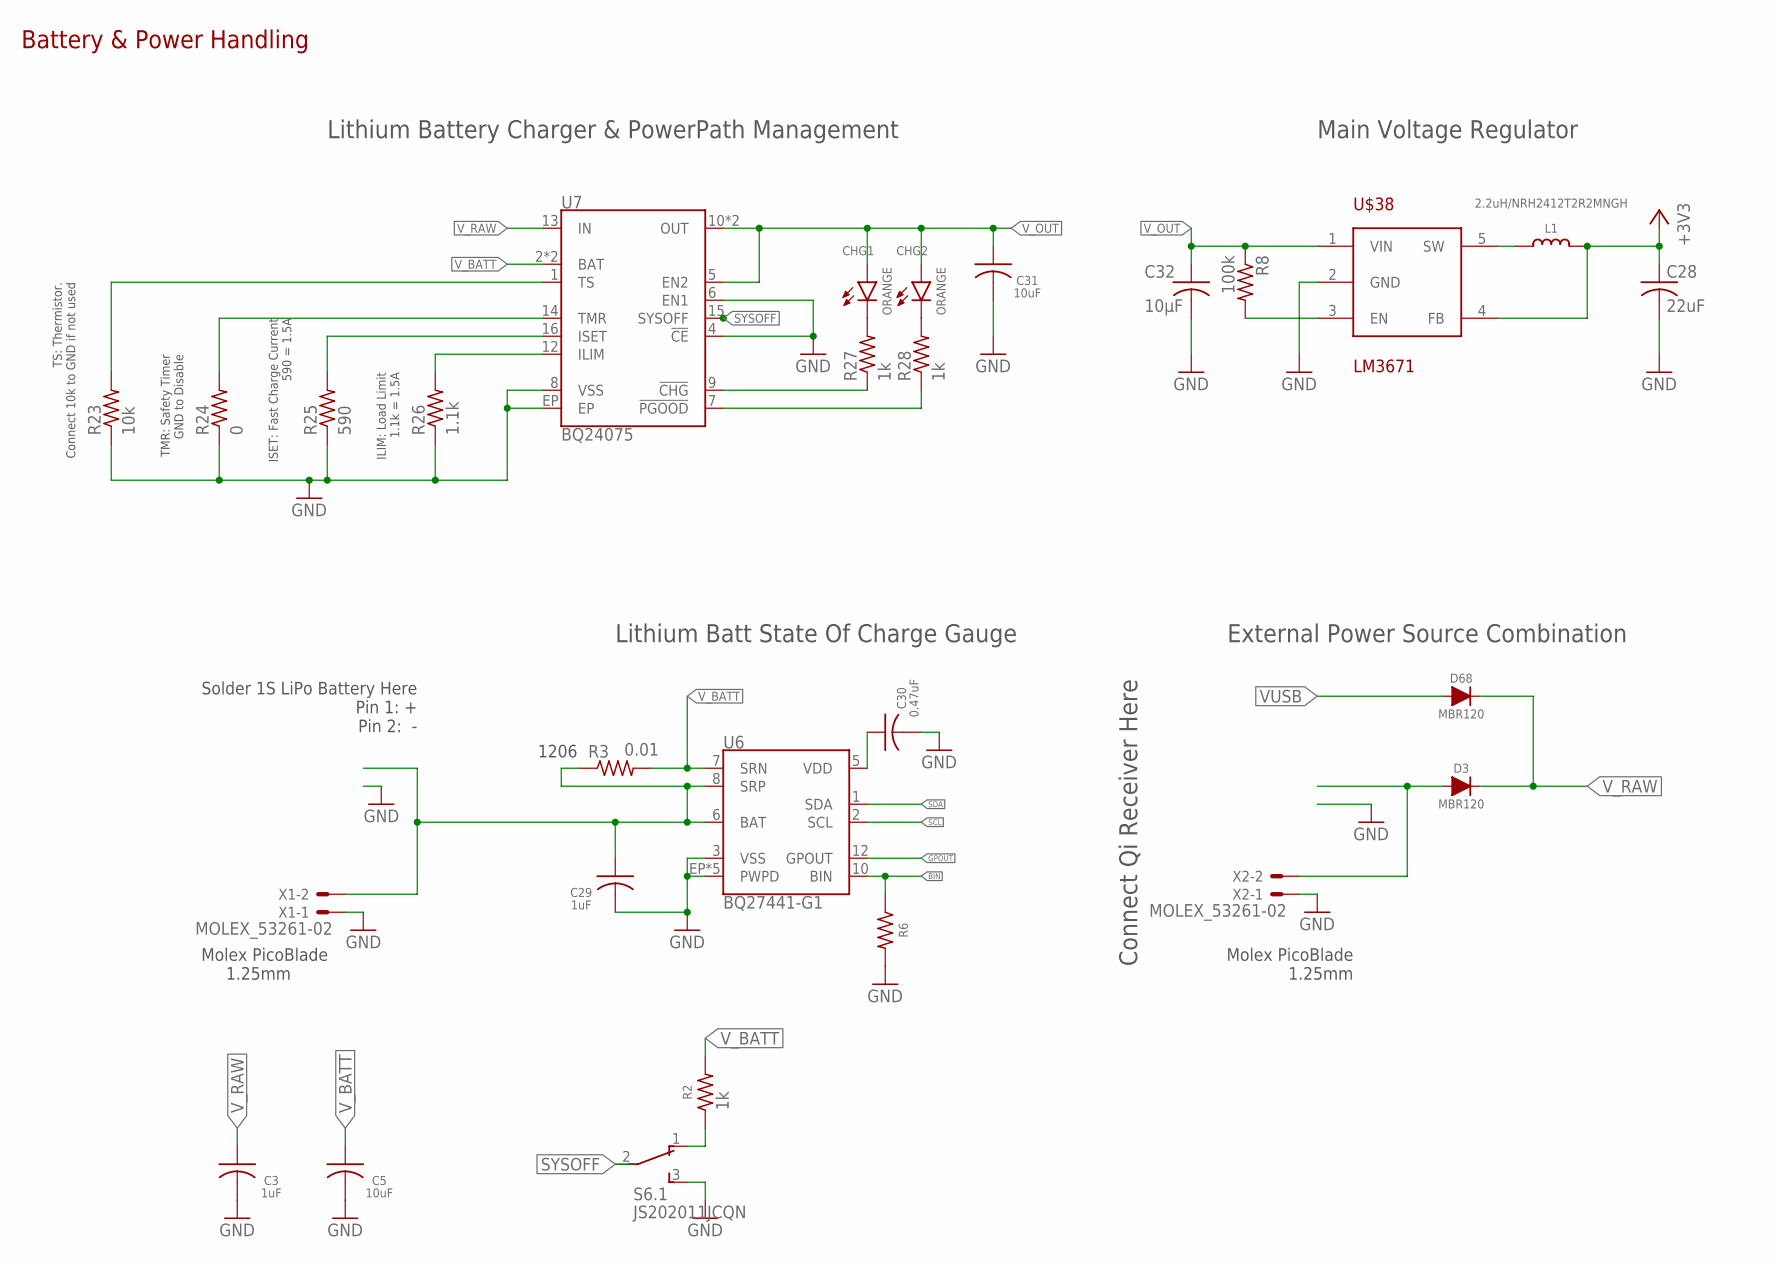
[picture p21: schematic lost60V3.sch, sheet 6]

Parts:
C3, C29: 1uF; C0603K
C5, C31: 10uF; C0603K
C28: 22uF; C0603K
C30: 0.47uF; C0603K
C32: 10µF; C0603K
CHG1, CHG2: ORANGE; LED-0603
D3, D68: MBR120; SOD123
L1: 2.2uH/NRH2412T2R2MNGH; MICROBUILDER_INDUCTOR_TAIYOYUDEN_NRH2412T
R2, R27, R28: 1k; R0603
R3: 0.01; R1206
R6: 2.7k; R0603
R8: 100k; R0603
R23: 10k; R0603
R24: 0; R0603
R25: 590; R0603
R26: 1.1k; R0603
S6: JS202011JCQN
U6: BQ27441-G1; PDSO-N12
U7: BQ24075; PVQFN-N16
U$38: LM3671; SOT23-5
X1, X2: MOLEX_53261-02; 53261-02

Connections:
+3V3: C28.1, L1.2, U$38.4 (FB); also elsewhere on the board
BATT_IN: C29.1, R3.1, U6.6 (BAT), U6.8 (SRP), X1.2
BIN: R6.1, U6.10 (BIN)
GND: C3.2, C5.2, C28.2, C29.2, C30.2, C31.2, C32.2, R6.2, R23.1, R24.1, R25.1, R26.1, S6.3 (S), U6.3 (VSS), U6.EP (PWPD), U6.EP1 (PWPD), U6.EP2 (PWPD), U6.EP3 (PWPD), U6.EP4 (PWPD), U7.4 (!CE!), U7.6 (EN1), U7.8 (VSS), U7.EP, U$38.2 (GND), X1.1, X2.1; also elsewhere on the board
GPOUT: U6.12 (GPOUT); also elsewhere on the board
unnamed: R2.1, S6.1 (O)
unnamed: D3.2 (A), X2.2
unnamed: L1.1, U$38.5 (SW)
unnamed: R23.2, U7.1 (TS)
unnamed: R24.2, U7.14 (TMR)
unnamed: C30.1, U6.5 (VDD)
unnamed: R8.2, U$38.3 (EN)
unnamed: R25.2, U7.16 (ISET)
unnamed: R26.2, U7.12 (ILIM)
unnamed: R27.1, U7.9 (!CHG!)
unnamed: CHG1.C, R27.2
unnamed: CHG2.C, R28.2
unnamed: R28.1, U7.7 (!PGOOD!)
SCL: U6.2 (SCL); also elsewhere on the board
SDA: U6.1 (SDA); also elsewhere on the board
SYSOFF: S6.2, U7.15 (SYSOFF)
VUSB: D68.2 (A); also elsewhere on the board
V_BATT: C5.1, R2.2, R3.2, U6.7 (SRN), U7.2 (BAT), U7.3 (BAT)
V_OUT: C31.1, C32.1, CHG1.A, CHG2.A, R8.1, U7.5 (EN2), U7.10 (OUT), U7.11 (OUT), U$38.1 (VIN); also elsewhere on the board
V_RAW: C3.1, D3.1 (C), D68.1 (C), U7.13 (IN)

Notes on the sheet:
Solder 1S LiPo Battery Here Pin 1: + Pin 2: -
Battery & Power Handling
Connect Qi Receiver Here
External Power Source Combination
Lithium Battery Charger & PowerPath Management
Main Voltage Regulator
Lithium Batt State Of Charge Gauge
Molex PicoBlade 1.25mm
1206
TS: Thermistor. Connect 10k to GND if not used
TMR: Safety Timer GND to Disable
ISET: Fast Charge Current 590 = 1.5A
ILIM: Load Limit 1.1k = 1.5A

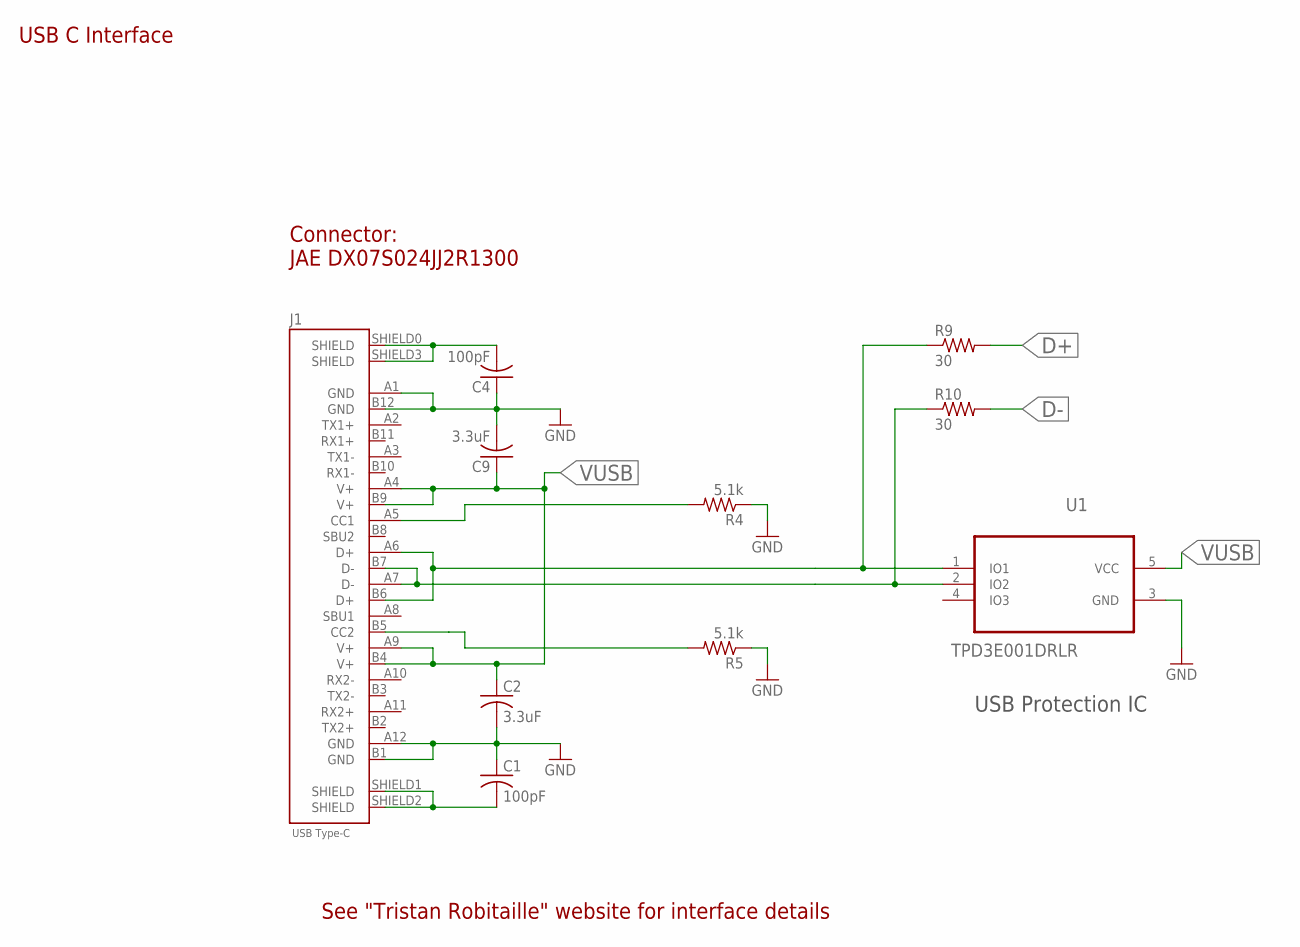
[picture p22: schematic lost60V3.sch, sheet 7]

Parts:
C1, C4: 100pF; C0603K
C2, C9: 3.3uF; C0603K
J1: DX07S024JJ2_USB_TYPE-C; DX07S0224JJ2_USB-C
R4, R5: 5.1k; R0603
R9, R10: 30; R0603
U1: TPD3E001DRLR; SOT50P160X60-5N

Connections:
D+: R9.2; also elsewhere on the board
D-: R10.2; also elsewhere on the board
GND: C1.1, C2.2, C4.1, C9.2, J1.A1 (GND), J1.A12 (GND), J1.B1 (GND), J1.B12 (GND), R4.1, R5.1, U1.3 (GND); also elsewhere on the board
unnamed: C4.2, J1.SHIELD0 (SHIELD), J1.SHIELD3 (SHIELD)
unnamed: C1.2, J1.SHIELD1 (SHIELD), J1.SHIELD2 (SHIELD)
unnamed: J1.B5 (CC2), R5.2
unnamed: J1.A7 (D-), J1.B7 (D-), R10.1, U1.2 (IO2)
unnamed: J1.A6 (D+), J1.B6 (D+), R9.1, U1.1 (IO1)
unnamed: J1.A5 (CC1), R4.2
VUSB: C2.1, C9.1, J1.A4 (V+), J1.A9 (V+), J1.B4 (V+), J1.B9 (V+), U1.5 (VCC); also elsewhere on the board

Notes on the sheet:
USB C Interface
Connector: JAE DX07S024JJ2R1300
See "Tristan Robitaille" website for interface details
USB Protection IC

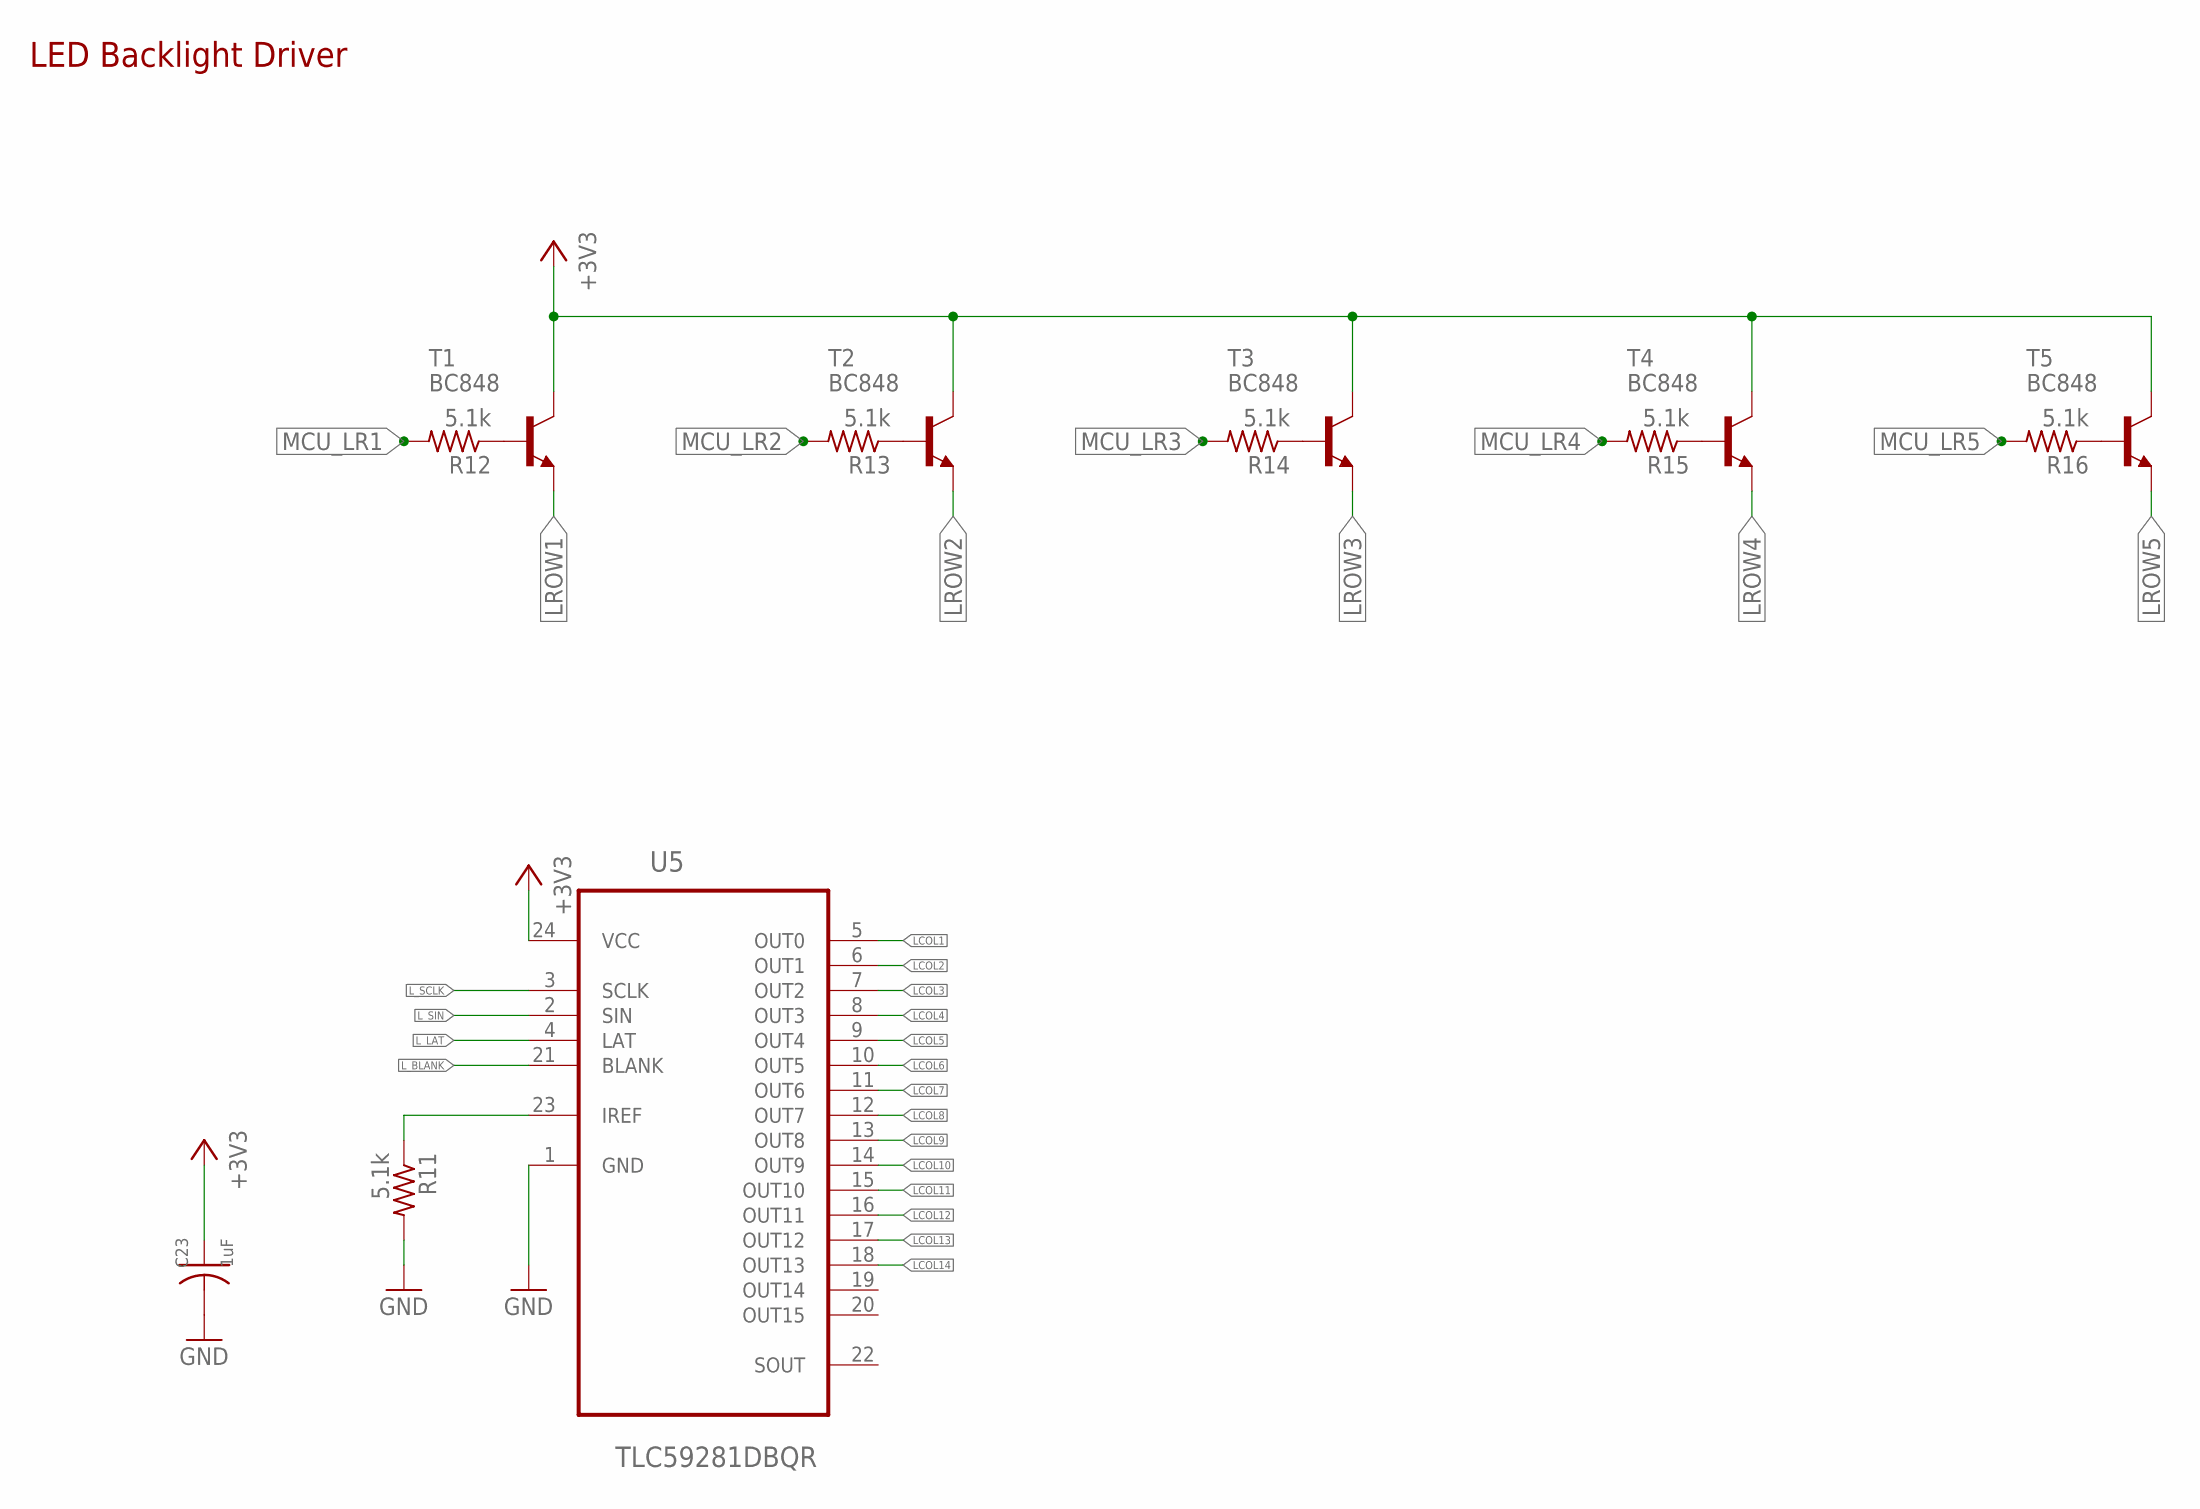
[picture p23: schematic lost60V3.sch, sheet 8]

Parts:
C23: 1uF; C0603K
R11, R12, R13, R14, R15, R16: 5.1k; R0603
T1, T2, T3, T4, T5: BC848; SOT23
U5: TLC59281DBQR; SOP63P600X175-28N

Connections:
+3V3: C23.1, T1.3 (C), T2.3 (C), T3.3 (C), T4.3 (C), T5.3 (C), U5.24 (VCC); also elsewhere on the board
GND: C23.2, R11.2, U5.1 (GND); also elsewhere on the board
LCOL1: U5.5 (OUT0); also elsewhere on the board
LCOL2: U5.6 (OUT1); also elsewhere on the board
LCOL3: U5.7 (OUT2); also elsewhere on the board
LCOL4: U5.8 (OUT3); also elsewhere on the board
LCOL5: U5.9 (OUT4); also elsewhere on the board
LCOL6: U5.10 (OUT5); also elsewhere on the board
LCOL7: U5.11 (OUT6); also elsewhere on the board
LCOL8: U5.12 (OUT7); also elsewhere on the board
LCOL9: U5.13 (OUT8); also elsewhere on the board
LCOL10: U5.14 (OUT9); also elsewhere on the board
LCOL11: U5.15 (OUT10); also elsewhere on the board
LCOL12: U5.16 (OUT11); also elsewhere on the board
LCOL13: U5.17 (OUT12); also elsewhere on the board
LCOL14: U5.18 (OUT13); also elsewhere on the board
LROW1: T1.2 (E); also elsewhere on the board
LROW2: T2.2 (E); also elsewhere on the board
LROW3: T3.2 (E); also elsewhere on the board
LROW4: T4.2 (E); also elsewhere on the board
LROW5: T5.2 (E); also elsewhere on the board
L_BLANK: U5.21 (BLANK); also elsewhere on the board
L_LAT: U5.4 (LAT); also elsewhere on the board
L_SCLK: U5.3 (SCLK); also elsewhere on the board
L_SIN: U5.2 (SIN); also elsewhere on the board
MCU_LR1: R12.2; also elsewhere on the board
MCU_LR2: R13.2; also elsewhere on the board
MCU_LR3: R14.2; also elsewhere on the board
MCU_LR4: R15.2; also elsewhere on the board
MCU_LR5: R16.2; also elsewhere on the board
unnamed: R11.1, U5.23 (IREF)
unnamed: R12.1, T1.1 (B)
unnamed: R13.1, T2.1 (B)
unnamed: R14.1, T3.1 (B)
unnamed: R15.1, T4.1 (B)
unnamed: R16.1, T5.1 (B)

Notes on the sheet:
LED Backlight Driver

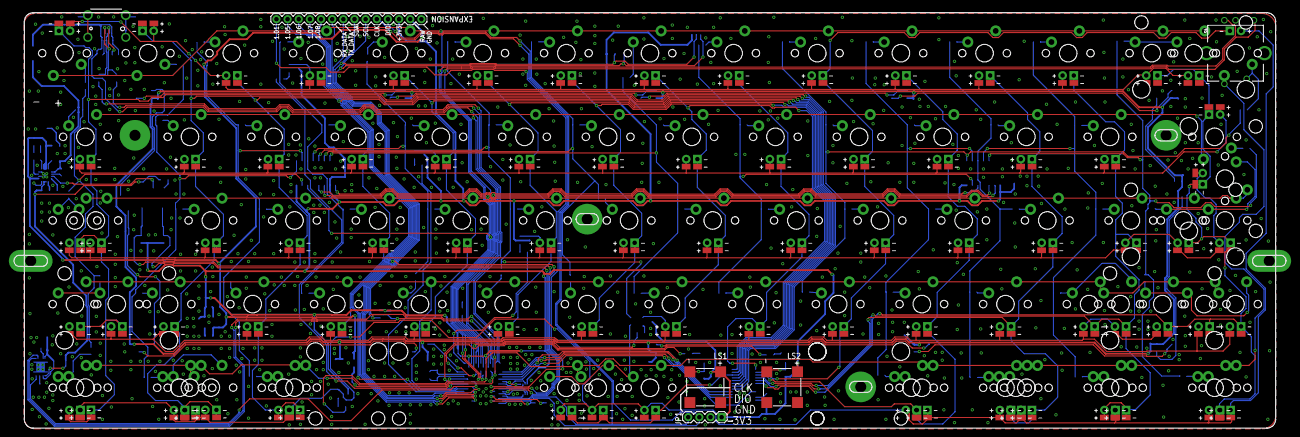
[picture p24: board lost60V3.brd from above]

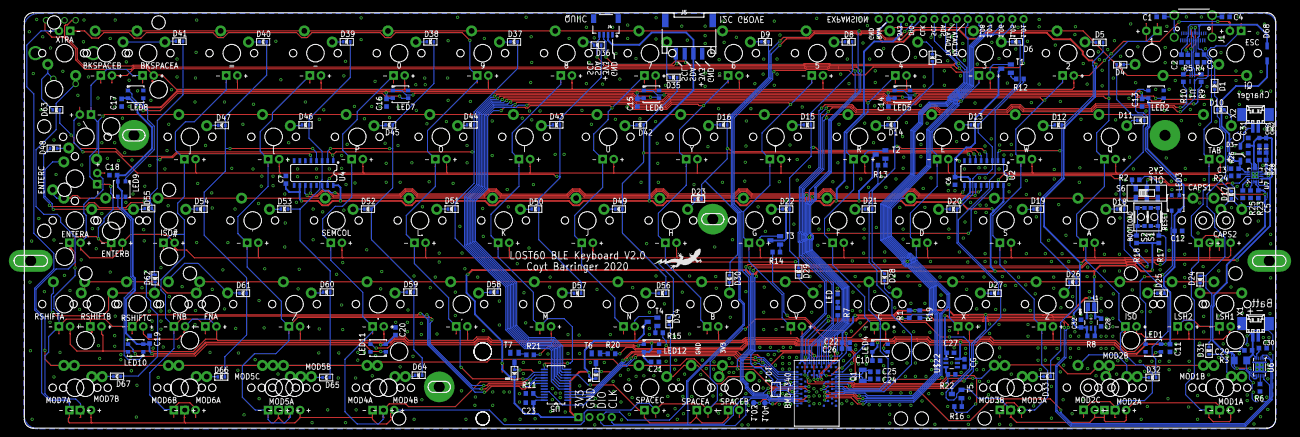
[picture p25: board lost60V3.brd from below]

Board: 2 copper layers, 289.7 x 95.4 mm, 268 parts (173 on the bottom side), 200 nets.

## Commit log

2020-04-19 initial add of media and design files
    [lost60V3.brd, lost60V3.sch]
2020-04-19 added bill of materials
    [LOST60_REV2_BOM.xlsx]

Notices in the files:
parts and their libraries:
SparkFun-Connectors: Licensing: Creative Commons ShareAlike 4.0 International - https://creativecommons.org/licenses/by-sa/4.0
